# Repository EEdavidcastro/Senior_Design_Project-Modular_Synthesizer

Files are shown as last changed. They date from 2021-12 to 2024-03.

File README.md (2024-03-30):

# EE485-Senior Design Project-Modular_Synth
This is the Senior Design project done by David Castro and Eric Burgess at CSUF in the fall semester of 2021 (August 2021 - December 2021) on building an Analog Modular Synthesizer

A video of the behavior of the Modular synthesizer can be seen on partner's youtube channel - https://www.youtube.com/watch?v=jhq_Q-R4t1U

The report, presentation, and virtual poster for a summary of the probject are also posted on this repository:
- Video (Partner's Youtube Channel): https://www.youtube.com/watch?v=jhq_Q-R4t1U
- Report: https://github.com/EEdavidcastro/EE485-SeniorDesign-Modular_Synth/blob/main/485Final%20Report_DavidCastro_EricBurgess.pdf
- Presentation: https://github.com/EEdavidcastro/EE485-SeniorDesign-Modular_Synth/blob/main/485Final%20Presentation_DavidCastro_EricBurgess.pdf
- Virtual Poster: https://github.com/EEdavidcastro/EE485-SeniorDesign-Modular_Synth/blob/main/485Final%20Project%20Poster%20Outline_David%20Castro%26EricBurgess.pdf

Note about uploaded files in the circuit design:
  - KiCad files for pcb design
  - .ms14 files are CAD files done in multisim software to show simulation of a small portion of the circuit (important part)

Note about MIDI Design: <br>
 - The current MIDI instrument is a modified version of Elkayem’s midi2cv design done by a youtuber named
“Benny Bones.” The MIDI gerber files and code to run the MIDI is provided in this respository for ease. **The MIDI was not designed by us due to time contraints.**

Note on file labeling mistake:
- Current Source file has files inside named VCF, ignore the title/label of it being VCF, they are the current source files

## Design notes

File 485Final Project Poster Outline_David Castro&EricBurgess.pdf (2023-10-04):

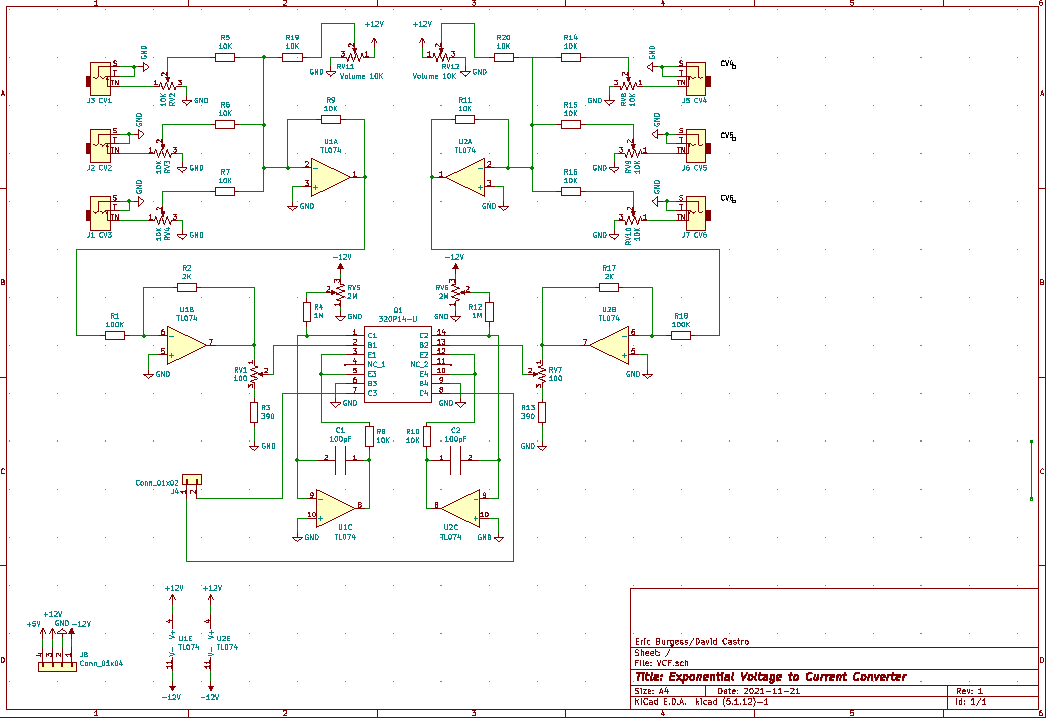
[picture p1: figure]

A modular synthesizer is an electronic device that consists of individual modules that can be connected by a user to create a music instrument. Modules specialize in a task such as creating a specific signal or affecting a signal in some way. For example, a sawtooth oscillator may be one module and a device to mix multiple signals together (a mixer) may be another. By connecting these devices together in various ways many sounds, and musical uses may be produced.

# Introduction

# Objectives

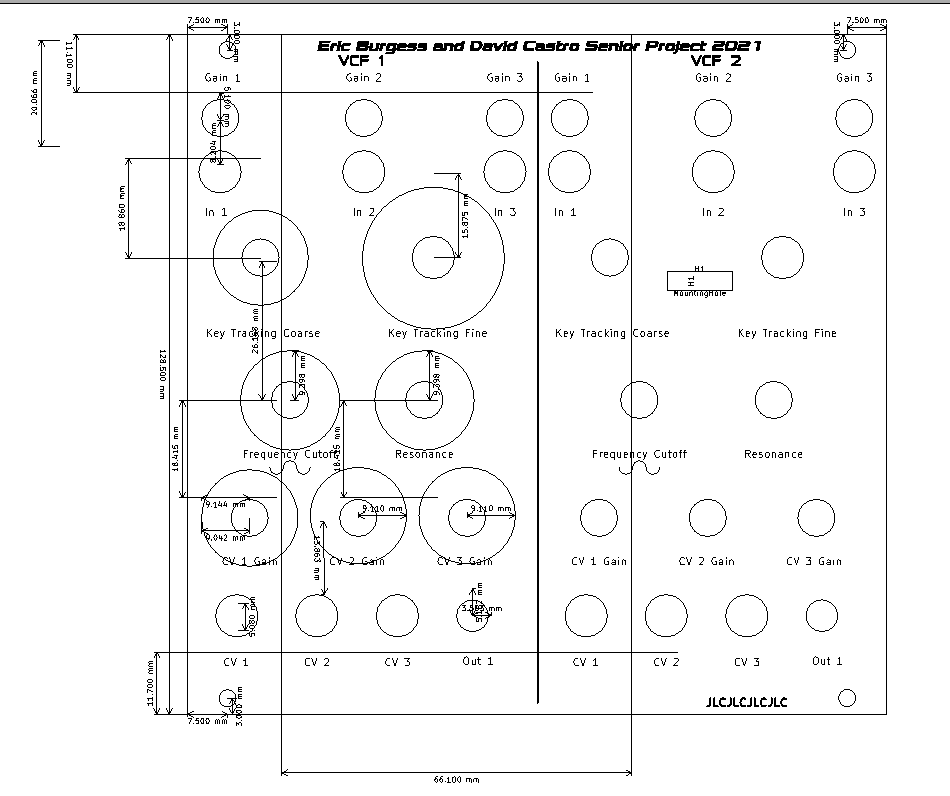
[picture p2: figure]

1. Circuits were designed and simulated in Multisim
2. The circuits were tested/built on a Bread board
3. Design EuroRack Standard Case
4. Were initially going to solder by hand, but decided upon using KiCad for PCB design and ordering the PCB’s from an online website
5. Panels/Covers were initially going to be done by hand but decided to use the KiCad and PCB material to act as the panels/covers
6. Solder the components onto the PCB and then screw everything together
7. Test and Debug the circuits to see if they properly work

# Steps of Design for Circuits

# Conclusion:

Power Supply
http://musicfromouterspace.com/analogsynth_new/WALLWARTSUPPLY/WALLWARTSUPPLY.phphttps://www.youtube.com/watch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

Synthesizer Modules
Textbook resources:
Musical Applications of Microprocessors (Hal Chamberlin) - chapter 6

Websites of Synthesizer Designs and Explanations: https://www.schmitzbits.de/expo_tutorial/index.html •ADSR design https://www.schmitzbits.de/adsr.htmlhttp://ijfritz.byethost4.com/sy_over.htm

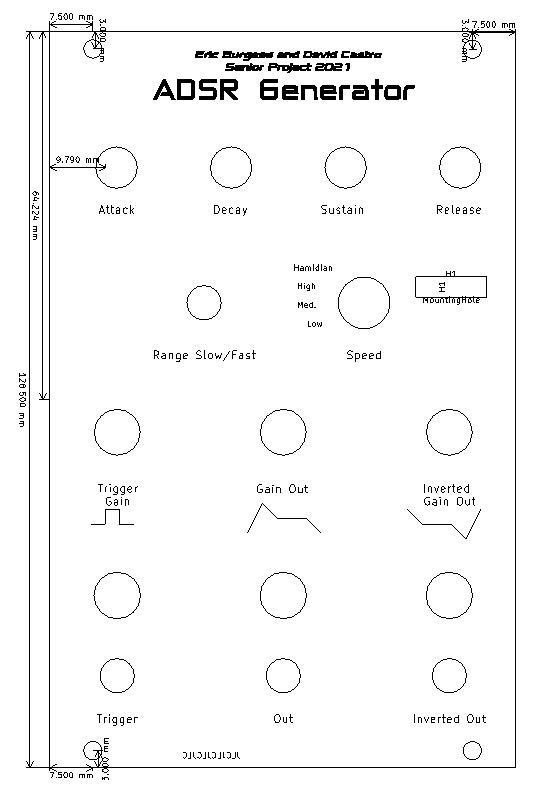
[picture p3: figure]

Georgia Tech Professor: - Aaron Lanterman Lectures:
VCA - https://www.youtube.com/watch?v=96j2tNKFCPI&t=202s
VCO - https://www.youtube.com/watch?v=qF4G4QfC9dM&t=699s
Exponential Voltage to Current - https://www.youtube.com/watch?v=ZWJhApUmfEU Playlist of Lectures:
https://www.youtube.com/playlist?list=PLOunECWxELQS5bMdWo9VhmZtsCjhjYNcV

Musical Instrument Digital Interface (MIDI)

Youtuber - Benny Bones: https://github.com/BennyBones/midi2cv

## GitHub Link of Final Report and all circuits and their designs in KiCad:

## https://github.com/EEdavidcastro/EE485-SeniorDesign-Modular_Synth

# Github Link

The end goal is to create enough modules and a variety of them to provide a versatile instrument. Specifically, we wish to create a power supply for the modules, an oscillator as a sound source, an ADSR envelope as a modulation signal, and a filter. All the modules should be voltage controlled, meaning they can be controlled by an input voltage from another module. A voltage to current exponential converter will be used to convert a controlled voltage (CV) to a controlled current. Doing this allows Operational Transconductance Amplifiers (OTA’s) to be used in circuit design as a way of adjusting each module. By having each module be voltage controlled, the modules will be able to interact and control each other.

# Layout of Voltage to Current Converter (KiCad)

Description: The circuit shows 2 voltage to current converter circuits. Each have 3 control voltage inputs that are mixed through an active mixing circuit. From there it flows through an op amp gain stage that is used to tune down the voltage that will flow into the base of a BJT differential pair. The IC chip (320P14) is just two matched differential pairs (PNP). Nearly the same circuit applies for the circuit above the sink version. The main difference is that NPN BJTS are used in the differential pair chip.

# Constraints of the Design

•The Power Supply will have outputs for +/- 12 Volts and +5 Volts. It will be able to take any U.S. standard outlet for supplying the power supply through a wall wart
•Patches to modules on the user side will be done with standard 3.5mm ⅛ inch mono jacks. Stereo jacks will be used where appropriate if needed.
•One Volt per octave is the standard for the voltage to current converters. This means for each volt, the current doubles meaning, the frequency of the oscillator will double. This is a common tuning standard so that voltages correspond with musical pitches.

# Voltage to Current Converter Circuit (source)

Description: The design were done in KiCad using the layout tool. It would be ideal for these to be done on aluminum sheets, but due the costs we decided on using PCB material, the same used for the circuits. This was done for each of the panels: VCA, VCF, ADSR Envelope, power supply, and MIDI device.

Description: The PCB board was designed as Though Hole (THT) with each of the chips, resistors, capacitors, etc inserted into the device. This process of PCB design is done for the VCO, VCA, and ADSR Envelope aswell.
Note: See Github link for the rest of the designs in KiCad

# Block Diagram

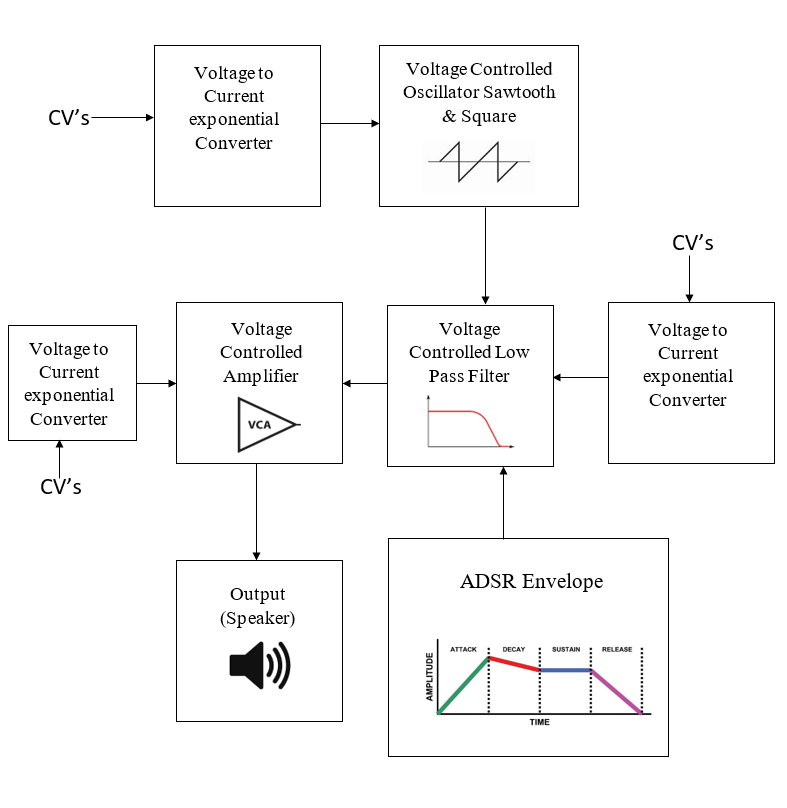
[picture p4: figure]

Description: This block diagram is an example of how the modules can be connected. The only thing standard is the CV’s and the voltage to current converters before each voltage-controlled module. A different way of connecting the modules could be having the ADSR envelope connected to the oscillator or amplifier instead

# Example of Cover Panel Design (VCF)

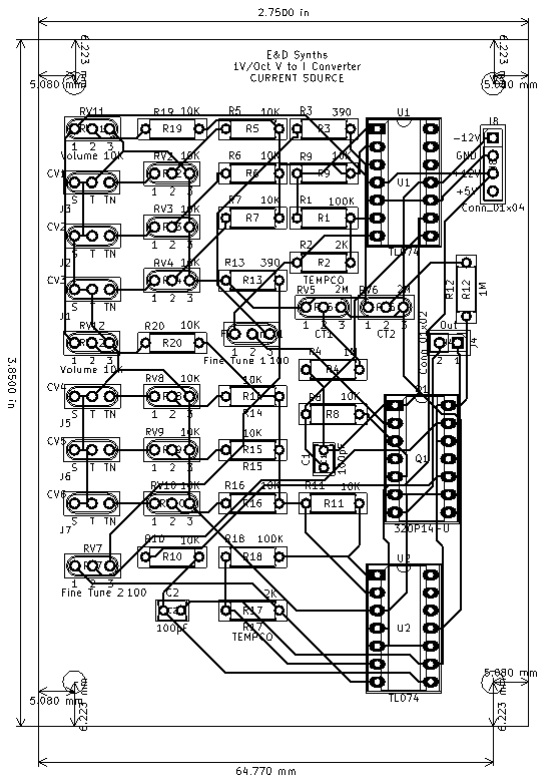
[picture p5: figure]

Description: Due to time constraint an auto router was used for the layout. KiCad does not have a built in autorouter, but there as exterior tool that can do autorouting of a KiCad design and then be imported. Besides the routing, each of the PCB’s were designed so that the screw holes would align up correctly with each other.

# Final Product Pictures:

# References

# Printed Board of Voltage to Current Converted:

There were many problems that came along the way in order to achieve the goal of this project. Some of the modules did not initially work and currently there are some things in the final product that need adjustment. The layout and schematic designs had some errors that caused the need for there to be some external wiring or modding of the PCB board. One example is that the +Vcc and -Vcc were mixed up on one IC which caused the need to do some wiring off board. This problem also occurred for the ADSR where the BJTS did not have the same pinout on the layout. Also, a few of the devices when put in the case ended up having some functionality problems. This occurs because there are many wires and no cable management which means the wires are most likely touching and creating connections when there should be none. One of the sawtooth oscillators for example is affected by the PWM adjustment of the square wave. This problem was not seen until the module was put in the case and is believed to be caused by some wires touching each other. Another problem seen when putting the module in the case is the VCF where for some reason things will stop working at certain moments or sometimes a potentiometer would affect the other VCF. These problems could be fixed with proper cable management, but overall, the modules can be seen as a success as things behave correctly for the most part. In conclusion, a modular synthesizer was achieved, but some things need to be ironed out for it to always work properly.

# Modular Synthesizer

# Eric Burgess and David Castro

# EE-485 Electrical Engineering Design Project Laboratory Fall 2021 Advisor - Dr. David Cheng

Inside Wiring
within the case

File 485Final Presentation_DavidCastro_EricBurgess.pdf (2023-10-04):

# Modular Synthesizer

# Eric Burgess and David Castro

## EE-485 Electrical Engineering Design Project Laboratory Fall 2021

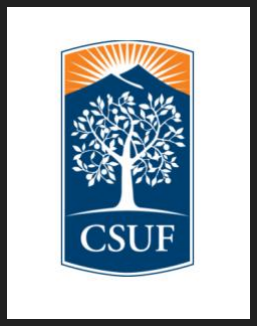
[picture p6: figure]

## Advisor - Dr. David Cheng

# What is a Synthesizer?

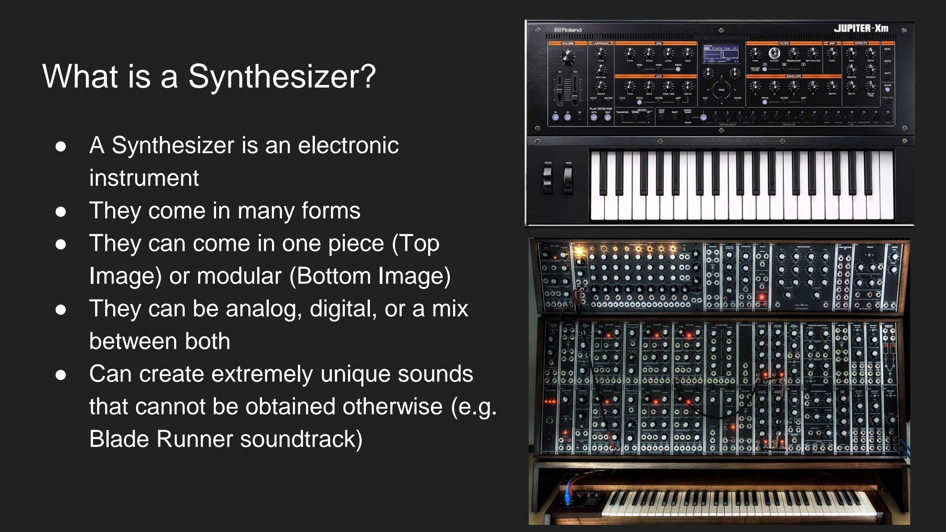
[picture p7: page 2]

## - A Synthesizer is an electronic instrument - They come in many forms - They can come in one piece (Top Image) or modular (Bottom Image) - They can be analog, digital, or a mix between both - Can create extremely unique sounds

that cannot be obtained otherwise (e.g.

## Blade Runner soundtrack)

# Our Synthesizer

## - We wanted a Modular Synthesizer

- Modular means each of the components are divided up - oscillators, filters, amplifiers, etc
- Benefits?
■ | Gives the user more freedom as things can be patched together by the user and there is
| not a set structure
- Components?
■ | VCO (Voltage Controlled Oscillator)
■ | VCA (Voltage Controlled Amplifier)
■ | VCF (Voltage Controlled Filter)
■ | ADSR Envelope Generator
■ | MIDI instrument
■ | Power Supply

# Block Diagram

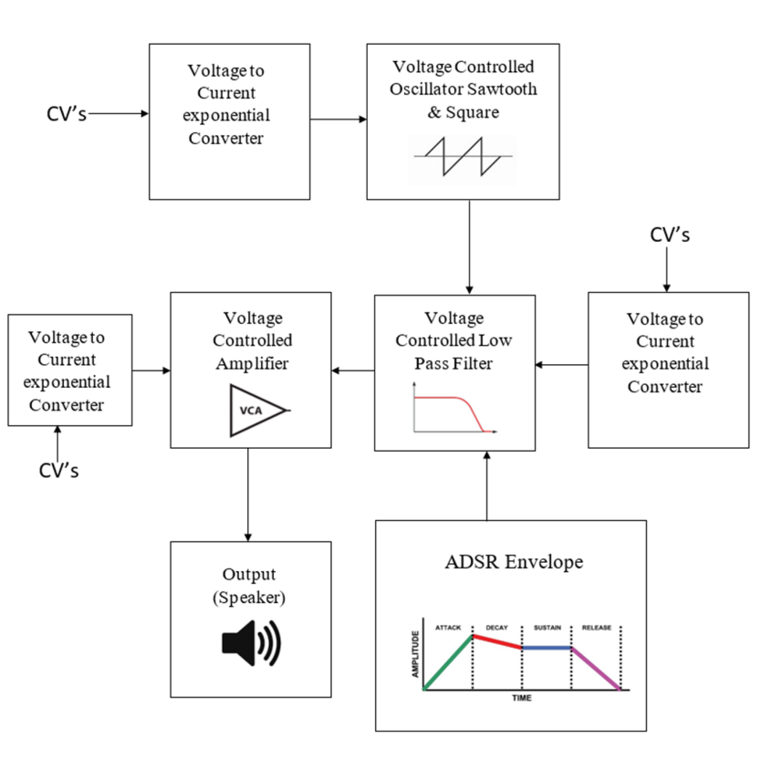
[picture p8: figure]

The system is modular, meaning the user can patch things together the way they want. The block diagram on the left is an example of how different modules can be connected

# Standards/Constraints

## Standards

### - 1 volt per Octave standard (This is a common tuning standard so that voltages correspond with musical pitches but we may choose to use another similar standard for the similar purpose of tuning)

## Constraints

### - Dual rail power supply. A positive and negative voltage will be available to run the system via a single wall wart. (+12V, -12V, GND) - Patches to modules on the user side will be done with standard 3.5mm ⅛ inch

mono jacks. Stereo jacks will be used where appropriate if needed.

# Power Supply Design

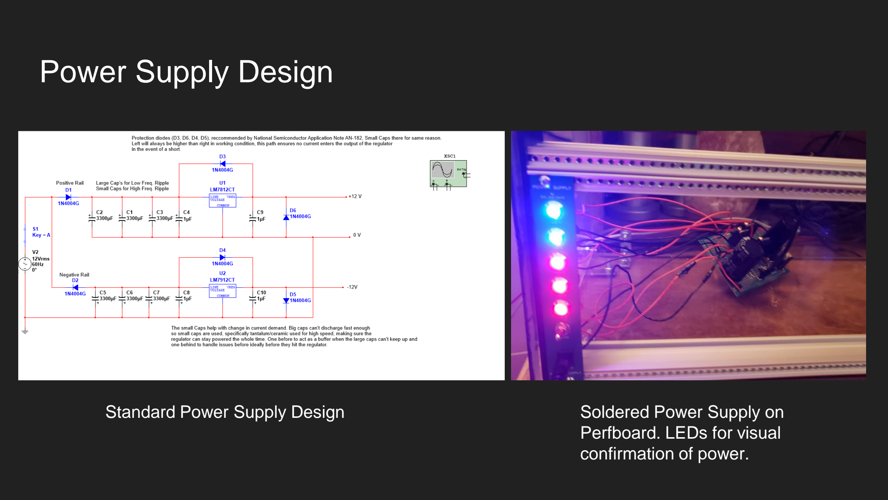
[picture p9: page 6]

Standard Power Supply Design | Soldered Power Supply on Perfboard. LEDs for visual confirmation of power.

# Another Picture of Power Supply

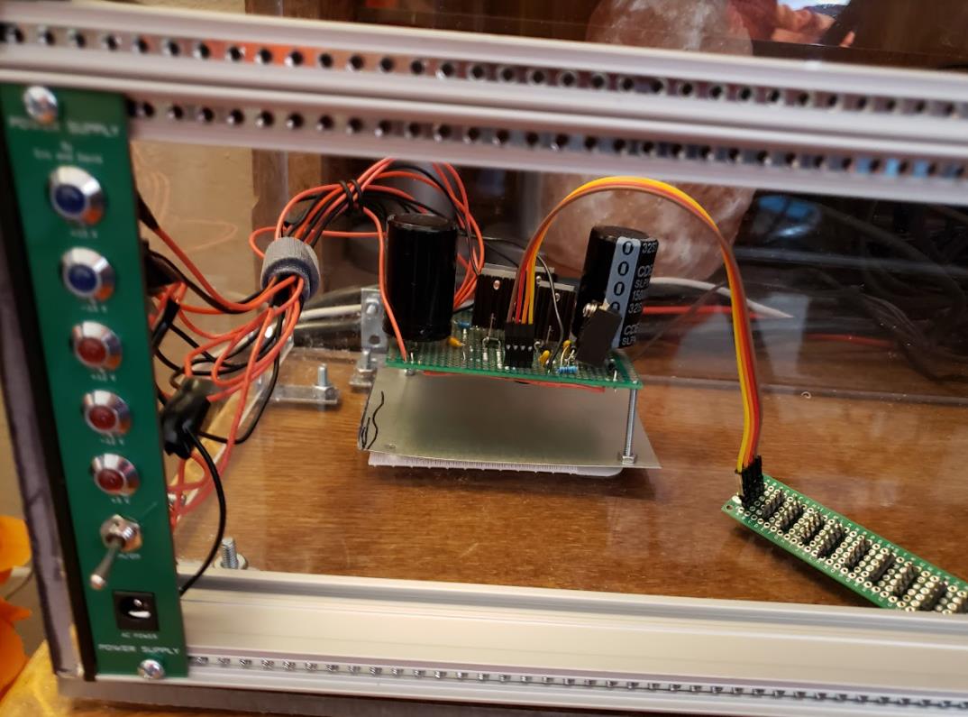
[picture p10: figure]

# VCO

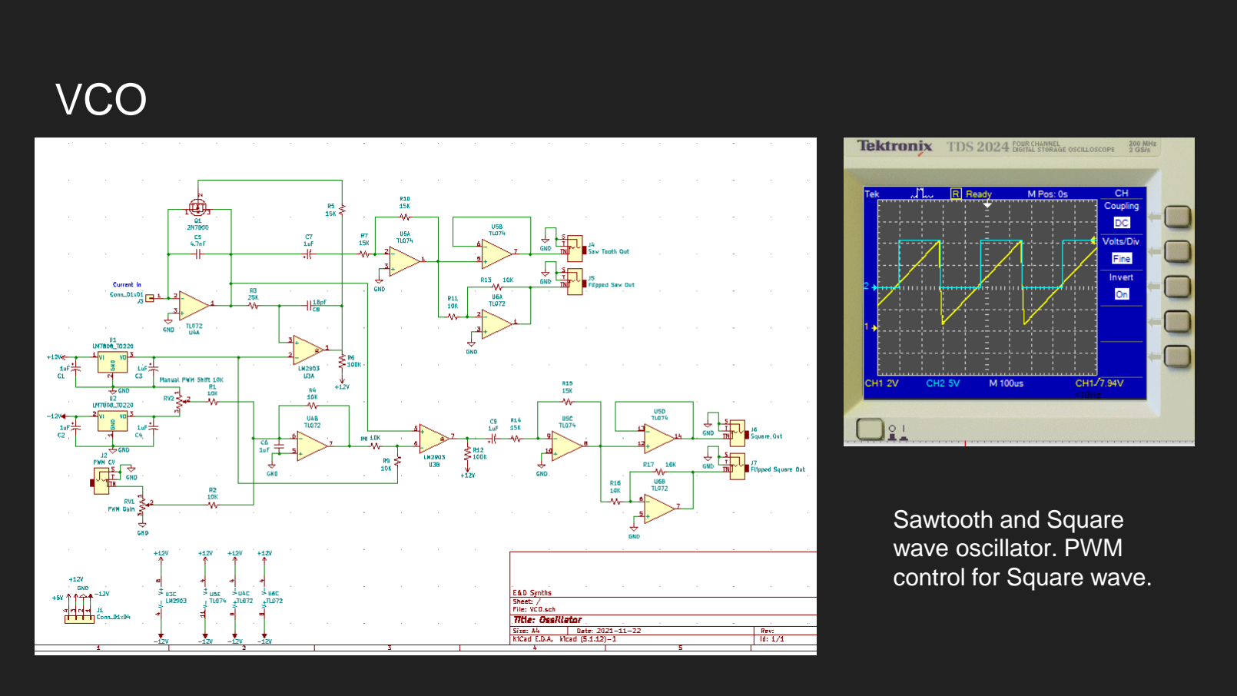
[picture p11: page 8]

Sawtooth and Square
wave oscillator. PWM
control for Square wave.

# VCF (Low-Pass)

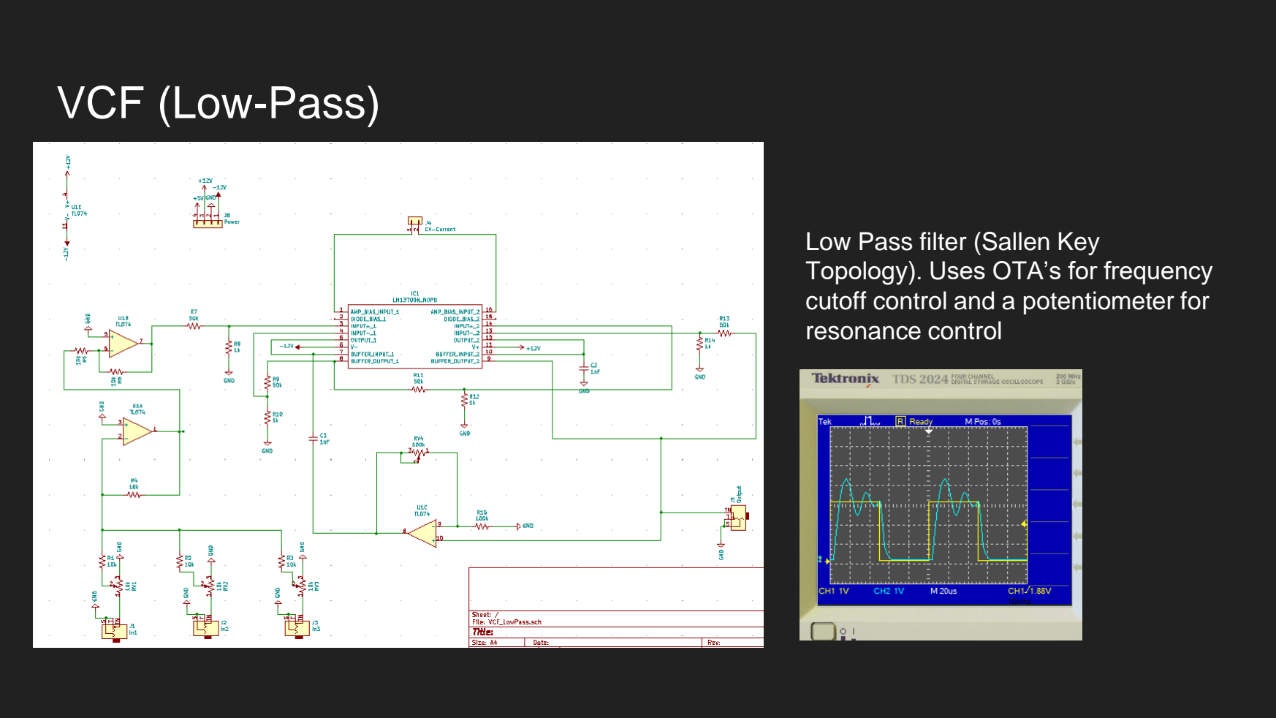
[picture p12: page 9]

Low Pass filter (Sallen Key Topology). Uses OTA’s for frequency cutoff control and a potentiometer for resonance control

# VCA

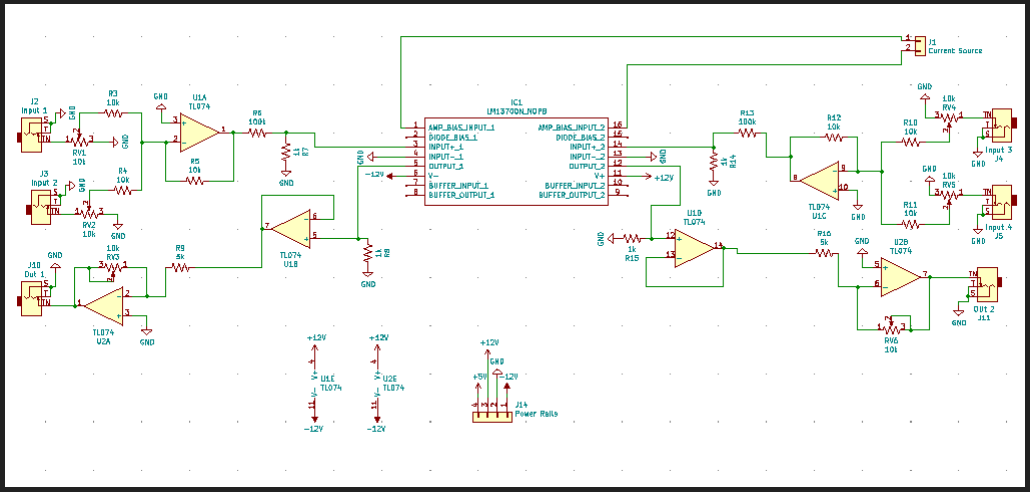
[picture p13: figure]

Uses OTA’s for
amplification. The
design has two
amplifiers on one
board.

# ADSR Envelope Generator

A - Attack
D - Decay
S - Sustain
R - Release

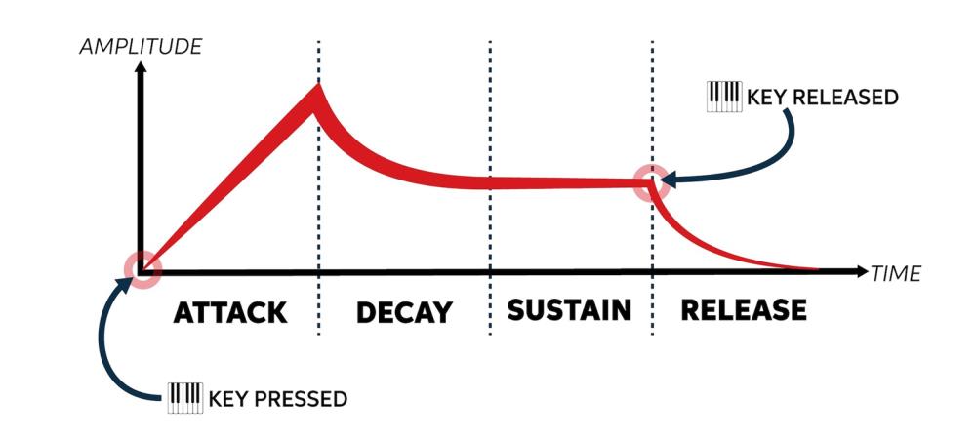
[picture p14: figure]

Important because its a voltage signal that can be adjusted. Our modules are voltage controlled so this can control the oscillator, filter, amplifier, etc

# ADSR Circuit

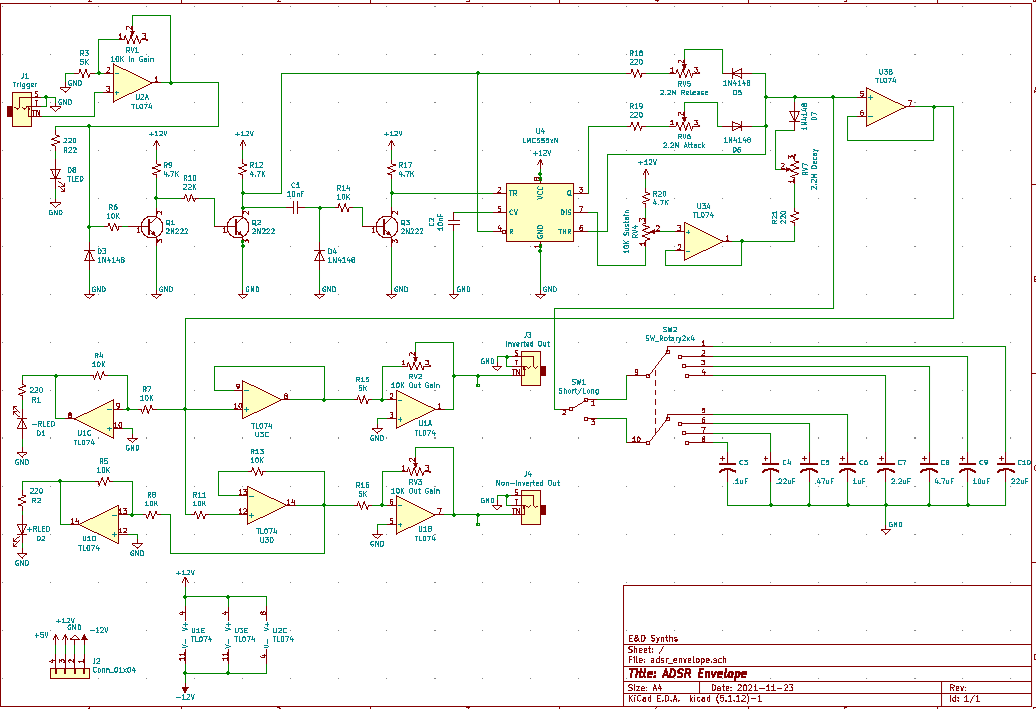
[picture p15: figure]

Capacitors control the time constant (charge and discharge rate). This design allows the user to switch between capacitors for different speeds in the ADSR

# Used KiCad for PCB Design

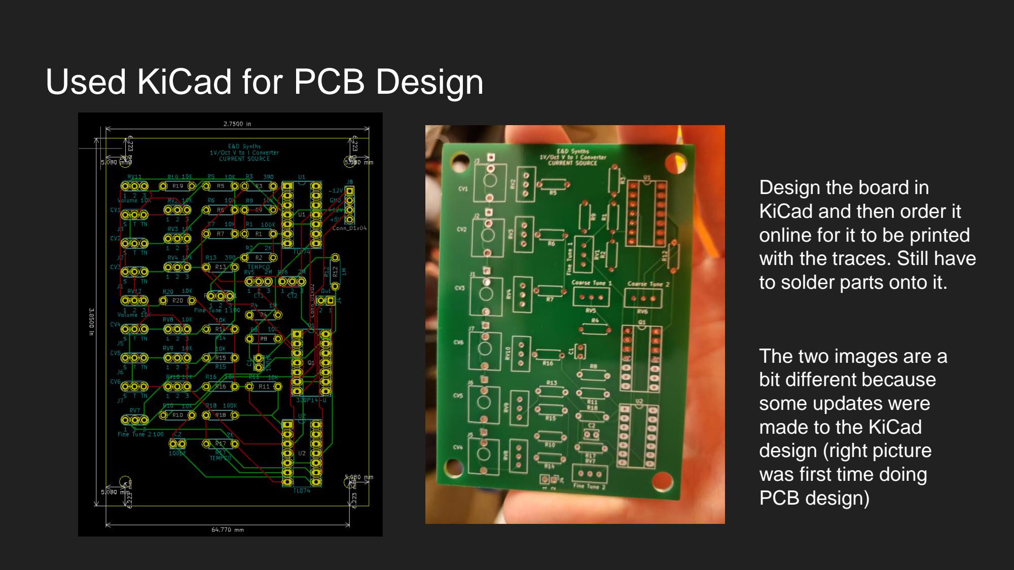
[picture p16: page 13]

Design the board in
KiCad and then order it
online for it to be printed with the traces. Still have to solder parts onto it.

The two images are a
bit different because
some updates were
made to the KiCad
design (right picture
was first time doing
PCB design)

# Completed ADSR

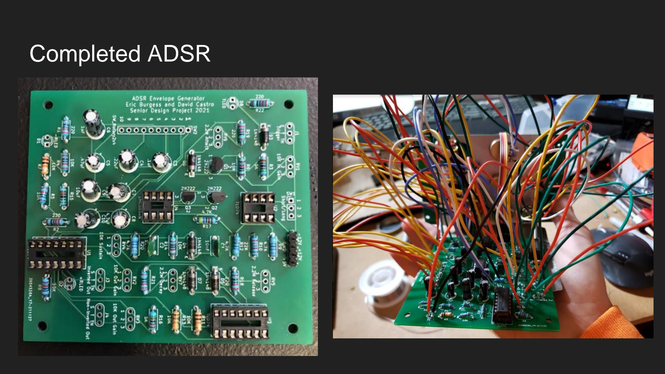
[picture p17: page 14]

# Putting Multiple Boards together

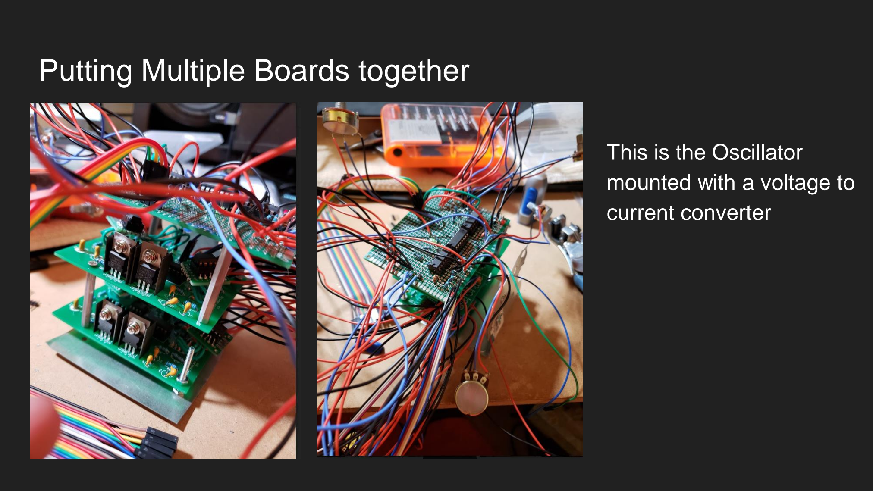
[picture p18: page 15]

## This is the Oscillator mounted with a voltage to current converter

# Panel Design (Done in KiCad)

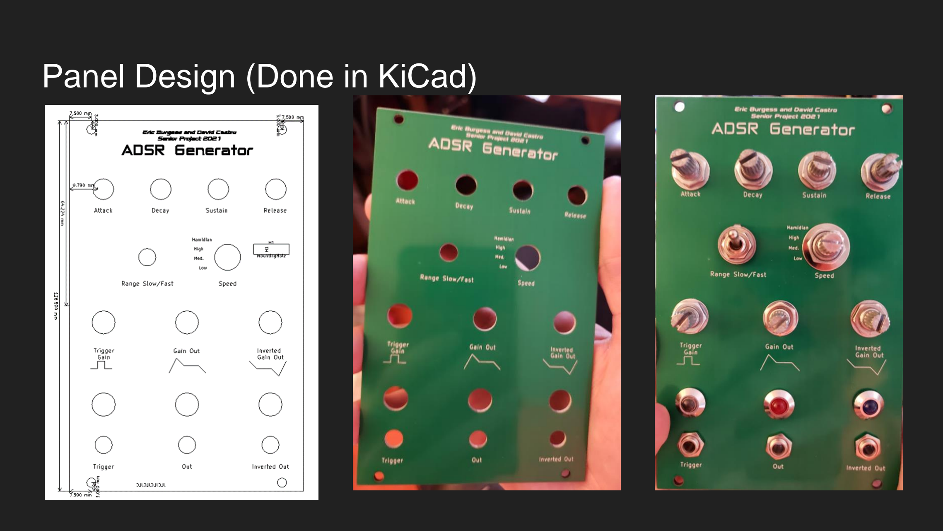
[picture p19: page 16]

# Mounting the Panel and PCB Board Together

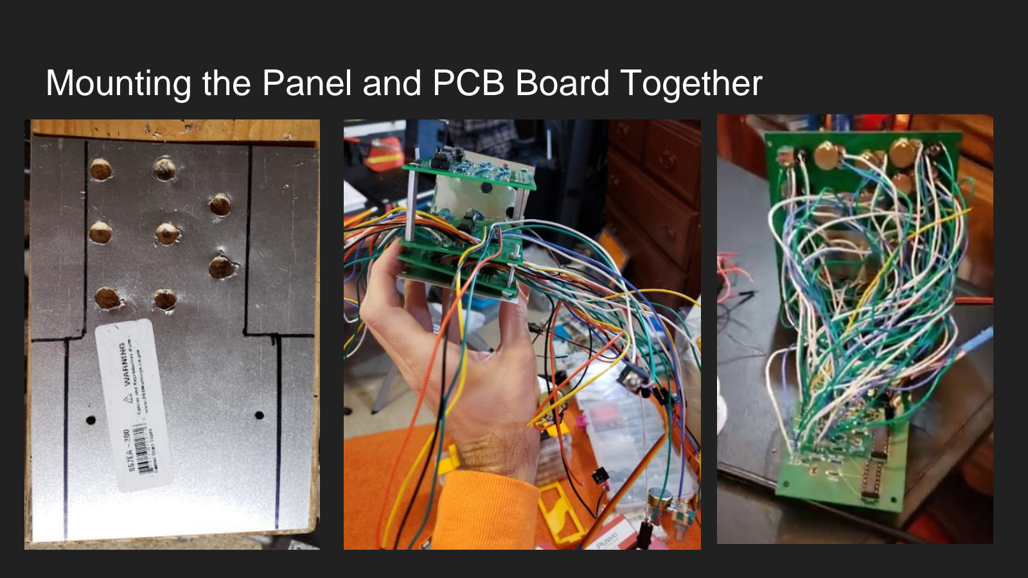
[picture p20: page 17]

# Case Design (EuroRack Standard)

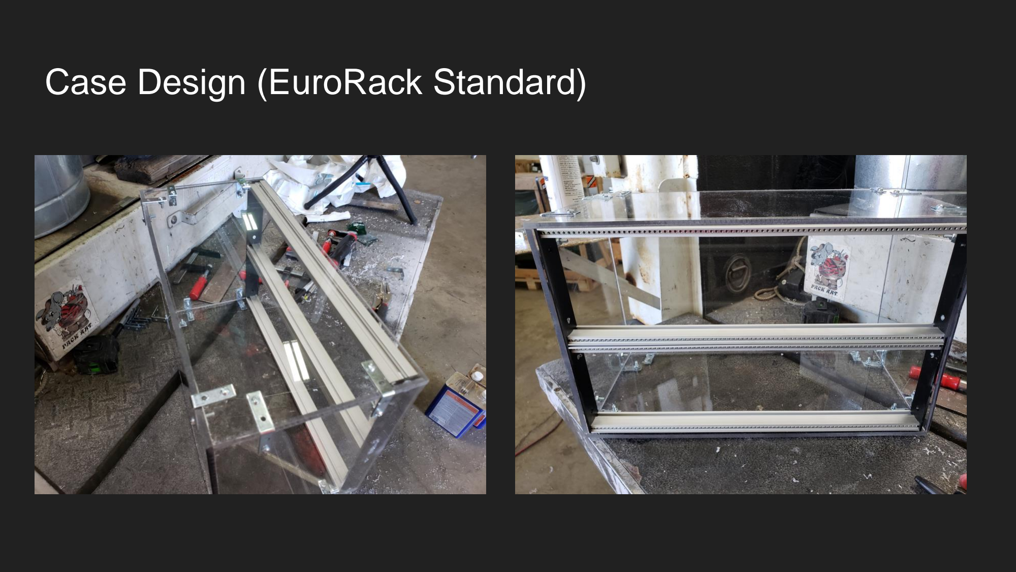
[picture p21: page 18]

# Final Product

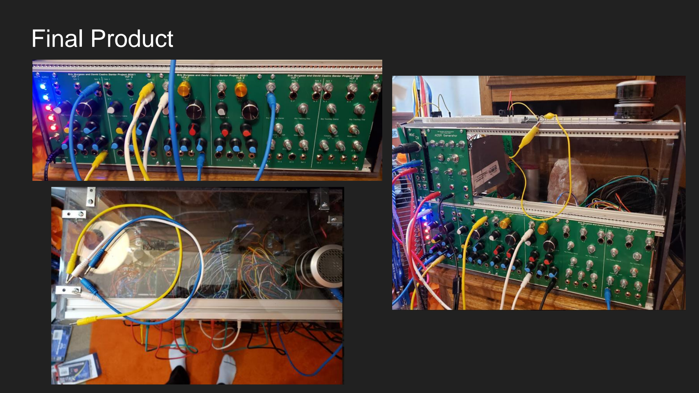
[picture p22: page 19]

# Does it work?

- It works. Although there was a lot of debugging/testing because the schematics/layouts had some slight errors - The VCF is the only really buggy module. The potentiometers/knobs affect things inconsistently. We believe this occurs because the wiring in the back is touching each other causing connections that shouldn’t be occurring - One of the sawtooths of the VCO’s also gets affected by the PWM. We know this is a cable management problem because this problem only started occurring when we put it in the case - Besides these two problems, things are good

# Last Topic - MIDI Instrument

- Musical Instrument Digital Interface (MIDI) - Outputs pulses (1’s and 0’s (Digital Signals)) as CV’s that end up getting converted to analog voltage signals through a Digital to Analog Converter and can then be fed into any of the modules - Important because it allows easy interface for the modules

# Some Video Links (Not the Final Product)

https://drive.google.com/file/d/1J7yfCgqspWNE97duwDbHwXujPmt6Wm02/view?usp=sharing -This showcases us debugging/testing the modules a bit

https://drive.google.com/file/d/1u8E_wDMR5lwQMjyUZ2qSCMlq0Rg5-qJn/view?usp=sharing -This one shows us testing the filter a bit

https://drive.google.com/file/d/1MLvvsz7yZ2b3NFyEDO3lgpPcuzt6oSCv/view?usp=sharing -Shows the frequency modulation that can be outputted from the Oscillator by inputting a control voltage from another oscillator

https://drive.google.com/file/d/1TYD_inGY7WyK13ahnys_tnFNM8BbnNII/view?usp=sharing - This one shows the VCO, VCA, and VCF working together (No ADSR or MIDI)

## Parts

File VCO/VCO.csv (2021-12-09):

Reference | Quantity | Value | Footprint | Datasheet
C1 C2 C3 C4 | 4 | 1uF | Capacitor_THT:CP_Radial_Tantal_D4.5mm_P2.50mm | ~
C5 | 1 | 4.7nF | Capacitor_THT:C_Disc_D6.0mm_W2.5mm_P5.00mm | ~
C6 | 1 | 1uF | Capacitor_THT:C_Disc_D6.0mm_W2.5mm_P5.00mm | ~
C7 C9 | 2 | 1uF | Capacitor_THT:CP_Radial_D6.3mm_P2.50mm | ~
C8 | 1 | 18pF | Capacitor_THT:C_Disc_D3.4mm_W2.1mm_P2.50mm | ~
J1 | 1 | Conn_01x04 | Connector_PinHeader_2.54mm:PinHeader_1x04_P2.54mm_Vertical | ~
J2 | 1 | PWM CV | Connector_Audio:Jack_3.5mm_QingPu_WQP-PJ398SM_Vertical_CircularHoles | ~
J3 | 1 | Conn_01x01 | Connector_PinHeader_2.54mm:PinHeader_1x01_P2.54mm_Vertical | ~
J4 | 1 | Saw Tooth Out | Connector_Audio:Jack_3.5mm_QingPu_WQP-PJ398SM_Vertical_CircularHoles | ~
J5 | 1 | Flipped Saw Out | Connector_Audio:Jack_3.5mm_QingPu_WQP-PJ398SM_Vertical_CircularHoles | ~
J6 | 1 | Square Out | Connector_Audio:Jack_3.5mm_QingPu_WQP-PJ398SM_Vertical_CircularHoles | ~
J7 | 1 | Flipped Square Out | Connector_Audio:Jack_3.5mm_QingPu_WQP-PJ398SM_Vertical_CircularHoles | ~
Q1 | 1 | 2N7000 | Package_TO_SOT_THT:TO-92L_HandSolder | ~
R1 R2 R4 R8 R9 R11 R13 R16 R17 | 9 | 10K | Resistor_THT:R_Axial_DIN0207_L6.3mm_D2.5mm_P7.62mm_Horizontal | ~
R3 | 1 | 25K | Resistor_THT:R_Axial_DIN0207_L6.3mm_D2.5mm_P7.62mm_Horizontal | ~
R5 R7 R10 R14 R15 | 5 | 15K | Resistor_THT:R_Axial_DIN0207_L6.3mm_D2.5mm_P7.62mm_Horizontal | ~
R6 R12 | 2 | 100K | Resistor_THT:R_Axial_DIN0207_L6.3mm_D2.5mm_P7.62mm_Horizontal | ~
RV1 | 1 | 10K | ECAD Models:Potentiometer_BaiHuiWeiYe | ~
RV2 | 1 | Manual PWM Shift 10K | ECAD Models:Potentiometer_BaiHuiWeiYe | ~
U1 U2 | 2 | LM7808_TO220 | Package_TO_SOT_THT:TO-220-3_Vertical | https://www.onsemi.cn/PowerSolutions/document/MC7800-D.PDF
U3 | 1 | LM2903 | Package_DIP:DIP-8_W7.62mm_Socket_LongPads | http://www.ti.com/lit/ds/symlink/lm393.pdf
U4 U6 | 2 | TL072 | Package_DIP:DIP-8_W7.62mm_Socket_LongPads | http://www.ti.com/lit/ds/symlink/tl071.pdf
U5 | 1 | TL074 | Package_DIP:DIP-14_W7.62mm_Socket_LongPads | http://www.ti.com/lit/ds/symlink/tl071.pdf

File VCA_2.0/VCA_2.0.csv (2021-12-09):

Source: | C:\Users\David Castro\Downloads\Senior Project\Senior Project\VCA_2.0\VCA_2.0.sch
Date: | 11/27/2021 6:58:21 PM
Tool: | Eeschema (5.1.12)-1
Generator: | D:\kicad\bin\scripting\plugins/bom_csv_grouped_by_value.py
Component Count: | 31
Individual Components:
Item | Qty | Reference(s) | Value | LibPart | Footprint | Datasheet | Description | Height | Manufacturer_Name | Manufacturer_Part_Number | Mouser Part Number | Mouser Price/Stock
 |  | IC1 | LM13700N_NOPB | SamacSys_Parts:LM13700N_NOPB | Package_DIP:DIP-16_W7.62mm_Socket_LongPads | http://www.ti.com/lit/ds/symlink/lm13700.pdf | Dual transconductance op amp,LM13700N Texas Instruments LM13700N/NOPB Dual Operational Amplifier Transconductance, 2MHz Push-Pull 3 to 28V, 16-Pin MDIP | 4.318 | Texas Instruments | LM13700N/NOPB | 926-LM13700N/NOPB | https://www.mouser.co.uk/ProductDetail/Texas-Instruments/LM13700N-NOPB?qs=X1J7HmVL2ZFKw9D7azZDXw%3D%3D
 |  | J1 | Current Source | Connector_Generic:Conn_01x02 | Connector_PinHeader_2.54mm:PinHeader_1x02_P2.54mm_Vertical | ~
 |  | J2 | Input 1 | Connector:AudioJack2_SwitchT | custom:THONK-AudioJack-PJ398SM-W3.5mm | ~
 |  | J3 | Input 2 | Connector:AudioJack2_SwitchT | custom:THONK-AudioJack-PJ398SM-W3.5mm | ~
 |  | J4 | Input 3 | Connector:AudioJack2_SwitchT | custom:THONK-AudioJack-PJ398SM-W3.5mm | ~
 |  | J5 | Input 4 | Connector:AudioJack2_SwitchT | custom:THONK-AudioJack-PJ398SM-W3.5mm | ~
 |  | J10 | Out 1 | Connector:AudioJack2_SwitchT | custom:THONK-AudioJack-PJ398SM-W3.5mm | ~
 |  | J11 | OUt 2 | Connector:AudioJack2_SwitchT | custom:THONK-AudioJack-PJ398SM-W3.5mm | ~
 |  | J14 | Power Rails | Connector_Generic:Conn_01x04 | Connector_PinHeader_2.54mm:PinHeader_1x04_P2.54mm_Vertical | ~
 |  | R3 | 10k | Device:R_US | Resistor_THT:R_Axial_DIN0207_L6.3mm_D2.5mm_P7.62mm_Horizontal | ~
 |  | R4 | 10k | Device:R_US | Resistor_THT:R_Axial_DIN0207_L6.3mm_D2.5mm_P7.62mm_Horizontal | ~
 |  | R5 | 10k | Device:R_US | Resistor_THT:R_Axial_DIN0207_L6.3mm_D2.5mm_P7.62mm_Horizontal | ~
 |  | R6 | 100k | Device:R_US | Resistor_THT:R_Axial_DIN0207_L6.3mm_D2.5mm_P7.62mm_Horizontal | ~
 |  | R7 | 1k | Device:R_US | Resistor_THT:R_Axial_DIN0207_L6.3mm_D2.5mm_P7.62mm_Horizontal | ~
 |  | R8 | 1k | Device:R_US | Resistor_THT:R_Axial_DIN0207_L6.3mm_D2.5mm_P7.62mm_Horizontal | ~
 |  | R9 | 5k | Device:R_US | Resistor_THT:R_Axial_DIN0207_L6.3mm_D2.5mm_P7.62mm_Horizontal | ~
 |  | R10 | 10k | Device:R_US | Resistor_THT:R_Axial_DIN0207_L6.3mm_D2.5mm_P7.62mm_Horizontal | ~
 |  | R11 | 10k | Device:R_US | Resistor_THT:R_Axial_DIN0207_L6.3mm_D2.5mm_P7.62mm_Horizontal | ~
 |  | R12 | 10k | Device:R_US | Resistor_THT:R_Axial_DIN0207_L6.3mm_D2.5mm_P7.62mm_Horizontal | ~
 |  | R13 | 100k | Device:R_US | Resistor_THT:R_Axial_DIN0207_L6.3mm_D2.5mm_P7.62mm_Horizontal | ~
 |  | R14 | 1k | Device:R_US | Resistor_THT:R_Axial_DIN0207_L6.3mm_D2.5mm_P7.62mm_Horizontal | ~
 |  | R15 | 1k | Device:R_US | Resistor_THT:R_Axial_DIN0207_L6.3mm_D2.5mm_P7.62mm_Horizontal | ~
 |  | R16 | 5k | Device:R_US | Resistor_THT:R_Axial_DIN0207_L6.3mm_D2.5mm_P7.62mm_Horizontal | ~
 |  | RV1 | 10k | Device:R_POT_US | custom:POT_3_THT | ~
 |  | RV2 | 10k | Device:R_POT_US | custom:POT_3_THT | ~
 |  | RV3 | 10k | Device:R_POT_US | custom:POT_3_THT | ~
 |  | RV4 | 10k | Device:R_POT_US | custom:POT_3_THT | ~
 |  | RV5 | 10k | Device:R_POT_US | custom:POT_3_THT | ~
 |  | RV6 | 10k | Device:R_POT_US | custom:POT_3_THT | ~
 |  | U1 | TL074 | Amplifier_Operational:TL074 | Package_DIP:DIP-14_W7.62mm_Socket_LongPads | http://www.ti.com/lit/ds/symlink/tl071.pdf
 |  | U2 | TL074 | Amplifier_Operational:TL074 | Package_DIP:DIP-14_W7.62mm_Socket_LongPads | http://www.ti.com/lit/ds/symlink/tl071.pdf
Collated Components:
Item | Qty | Reference(s) | Value | LibPart | Footprint | Datasheet | Description | Height | Manufacturer_Name | Manufacturer_Part_Number | Mouser Part Number | Mouser Price/Stock
1 | 1 | IC1 | LM13700N_NOPB | SamacSys_Parts:LM13700N_NOPB | Package_DIP:DIP-16_W7.62mm_Socket_LongPads | http://www.ti.com/lit/ds/symlink/lm13700.pdf | Dual transconductance op amp,LM13700N Texas Instruments LM13700N/NOPB Dual Operational Amplifier Transconductance, 2MHz Push-Pull 3 to 28V, 16-Pin MDIP | 4.318 | Texas Instruments | LM13700N/NOPB | 926-LM13700N/NOPB | https://www.mouser.co.uk/ProductDetail/Texas-Instruments/LM13700N-NOPB?qs=X1J7HmVL2ZFKw9D7azZDXw%3D%3D
2 | 1 | J1 | Current Source | Connector_Generic:Conn_01x02 | Connector_PinHeader_2.54mm:PinHeader_1x02_P2.54mm_Vertical | ~
3 | 1 | J2 | Input 1 | Connector:AudioJack2_SwitchT | custom:THONK-AudioJack-PJ398SM-W3.5mm | ~
4 | 1 | J3 | Input 2 | Connector:AudioJack2_SwitchT | custom:THONK-AudioJack-PJ398SM-W3.5mm | ~
5 | 1 | J4 | Input 3 | Connector:AudioJack2_SwitchT | custom:THONK-AudioJack-PJ398SM-W3.5mm | ~
6 | 1 | J5 | Input 4 | Connector:AudioJack2_SwitchT | custom:THONK-AudioJack-PJ398SM-W3.5mm | ~
7 | 1 | J10 | Out 1 | Connector:AudioJack2_SwitchT | custom:THONK-AudioJack-PJ398SM-W3.5mm | ~
8 | 1 | J11 | OUt 2 | Connector:AudioJack2_SwitchT | custom:THONK-AudioJack-PJ398SM-W3.5mm | ~
9 | 1 | J14 | Power Rails | Connector_Generic:Conn_01x04 | Connector_PinHeader_2.54mm:PinHeader_1x04_P2.54mm_Vertical | ~
10 | 6 | R3, R4, R5, R10, R11, R12 | 10k | Device:R_US | Resistor_THT:R_Axial_DIN0207_L6.3mm_D2.5mm_P7.62mm_Horizontal | ~
11 | 2 | R6, R13 | 100k | Device:R_US | Resistor_THT:R_Axial_DIN0207_L6.3mm_D2.5mm_P7.62mm_Horizontal | ~
12 | 4 | R7, R8, R14, R15 | 1k | Device:R_US | Resistor_THT:R_Axial_DIN0207_L6.3mm_D2.5mm_P7.62mm_Horizontal | ~
13 | 2 | R9, R16 | 5k | Device:R_US | Resistor_THT:R_Axial_DIN0207_L6.3mm_D2.5mm_P7.62mm_Horizontal | ~
14 | 6 | RV1, RV2, RV3, RV4, RV5, RV6 | 10k | Device:R_POT_US | custom:POT_3_THT | ~
15 | 2 | U1, U2 | TL074 | Amplifier_Operational:TL074 | Package_DIP:DIP-14_W7.62mm_Socket_LongPads | http://www.ti.com/lit/ds/symlink/tl071.pdf

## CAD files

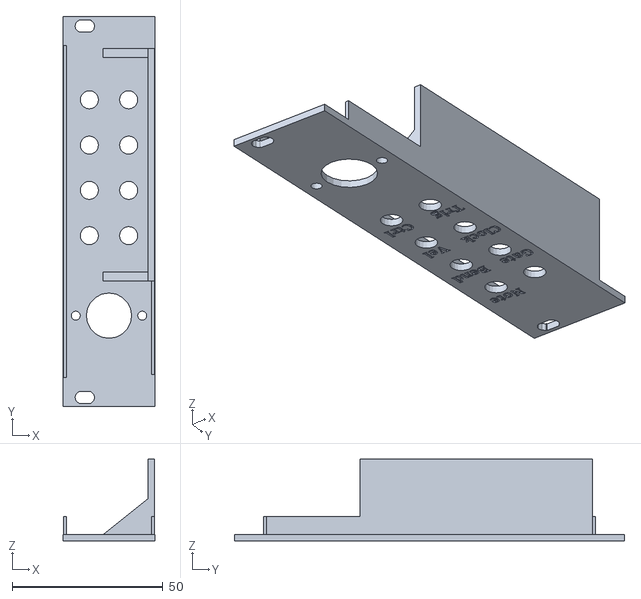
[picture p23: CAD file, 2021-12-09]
midi2cv-master/3dPrint/CV2Midi_face.stl
30.5 x 129.2 x 27.0

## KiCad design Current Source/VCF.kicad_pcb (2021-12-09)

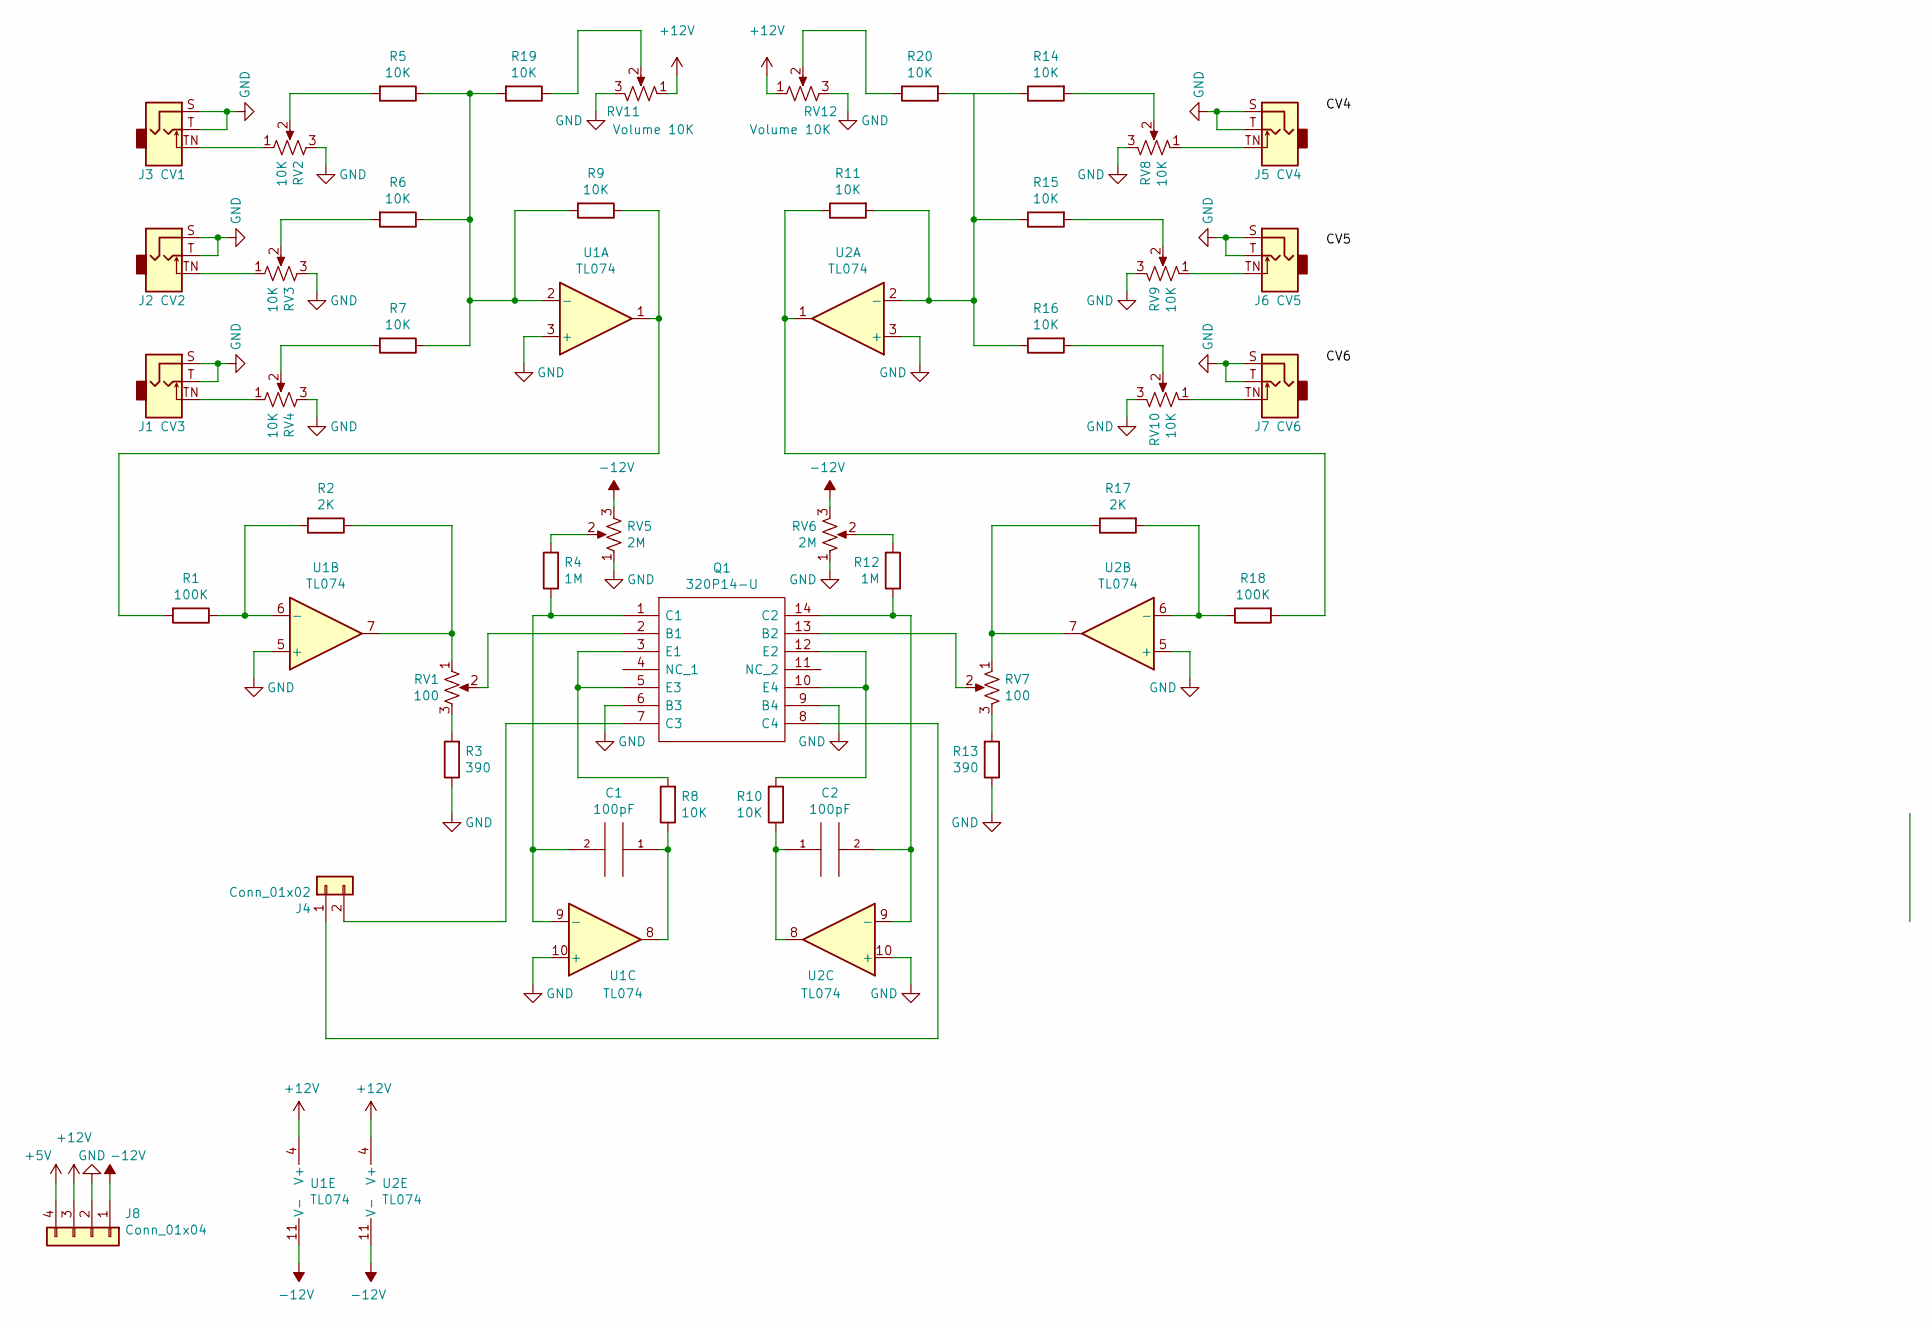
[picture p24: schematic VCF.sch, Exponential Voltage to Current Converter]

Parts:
C1, C2: 100pF; C_Disc_D3.8mm_W2.6mm_P2.50mm
J1: CV3; Thonkiconn_Audio_Jack_PJ398SM_W7.0mm_H2.5mm
J2: CV2; Thonkiconn_Audio_Jack_PJ398SM_W7.0mm_H2.5mm
J3: CV1; Thonkiconn_Audio_Jack_PJ398SM_W7.0mm_H2.5mm
J4: Conn_01x02; PinHeader_1x02_P2.54mm_Vertical
J5: CV4; Thonkiconn_Audio_Jack_PJ398SM_W7.0mm_H2.5mm
J6: CV5; Thonkiconn_Audio_Jack_PJ398SM_W7.0mm_H2.5mm
J7: CV6; Thonkiconn_Audio_Jack_PJ398SM_W7.0mm_H2.5mm
J8: Conn_01x04; PinHeader_1x04_P2.54mm_Vertical
Q1: 320P14-U; DIP-14_W7.62mm_Socket_LongPads; Manufacturer_Part_Number 320P14-U; Mouser Part Number 887-320P14-U
R1, R18: 100K; R_Axial_DIN0207_L6.3mm_D2.5mm_P7.62mm_Horizontal
R2, R17: 2K; R_Axial_DIN0207_L6.3mm_D2.5mm_P7.62mm_Horizontal
R3, R13: 390; R_Axial_DIN0207_L6.3mm_D2.5mm_P7.62mm_Horizontal
R4, R12: 1M; R_Axial_DIN0207_L6.3mm_D2.5mm_P7.62mm_Horizontal
R5, R6, R7, R8, R9, R10, R11, R14, R15, R16, R19, R20: 10K; R_Axial_DIN0207_L6.3mm_D2.5mm_P7.62mm_Horizontal
RV1, RV7: 100; Pot_Small_Mounting_W7.0mm_H2.5mm
RV2, RV3, RV4, RV8, RV9, RV10: 10K; Pot_Small_Mounting_W7.0mm_H2.5mm
RV5, RV6: 2M; Pot_Small_Mounting_W7.0mm_H2.5mm
RV11, RV12: Volume 10K; Pot_Small_Mounting_W7.0mm_H2.5mm
U1, U2: TL074; DIP-14_W7.62mm_Socket_LongPads

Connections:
+5V: J8.4
+12V: J8.3, RV11.1, RV12.1, U1.4 (V+), U2.4 (V+)
-12V: J8.1, RV5.3, RV6.3, U1.11 (V-), U2.11 (V-)
GND: J1.S, J1.T, J2.S, J2.T, J3.S, J3.T, J5.S, J5.T, J6.S, J6.T, J7.S, J7.T, J8.2, Q1.6 (B3), Q1.9 (B4), R3.1, R13.1, RV2.3, RV3.3, RV4.3, RV5.1, RV6.1, RV8.3, RV9.3, RV10.3, RV11.3, RV12.3, U1.3 (+), U1.5 (+), U1.10 (+), U2.3 (+), U2.5 (+), U2.10 (+)
unnamed: C1.1, R8.1, U1.8
unnamed: C1.2, Q1.1 (C1), R4.1, U1.9 (-)
unnamed: C2.1, R10.1, U2.8
unnamed: C2.2, Q1.14 (C2), R12.1, U2.9 (-)
unnamed: J1.TN, RV4.1
unnamed: J2.TN, RV3.1
unnamed: J3.TN, RV2.1
unnamed: J4.1, Q1.8 (C4)
unnamed: J4.2, Q1.7 (C3)
unnamed: J5.TN, RV8.1
unnamed: J6.TN, RV9.1
unnamed: J7.TN, RV10.1
unnamed 16: Q1.2 (B1), RV1.2; also elsewhere on the board
unnamed: Q1.3 (E1), Q1.5 (E3), R8.2
unnamed: Q1.10 (E4), Q1.12 (E2), R10.2
unnamed: Q1.13 (B2), RV7.2
unnamed: R1.1, R2.2, U1.6 (-)
unnamed: R1.2, R9.1, U1.1
unnamed 24: R2.1, RV1.1, U1.7; also elsewhere on the board
unnamed 25: R3.2, RV1.3; also elsewhere on the board
unnamed: R4.2, RV5.2
unnamed: R5.2, RV2.2
unnamed: R6.2, RV3.2
unnamed: R7.2, RV4.2
unnamed: R11.1, R18.2, U2.1
unnamed: R11.2, R14.1, R15.1, R16.1, R20.2, U2.2 (-)
unnamed: R12.2, RV6.2
unnamed: R13.2, RV7.3
unnamed: R14.2, RV8.2
unnamed: R15.2, RV9.2
unnamed: R16.2, RV10.2
unnamed: R17.1, RV7.1, U2.7
unnamed: R17.2, R18.1, U2.6 (-)
unnamed: R19.1, RV11.2
unnamed: R5.1, R6.1, R7.1, R9.2, R19.2, U1.2 (-)
unnamed: R20.1, RV12.2

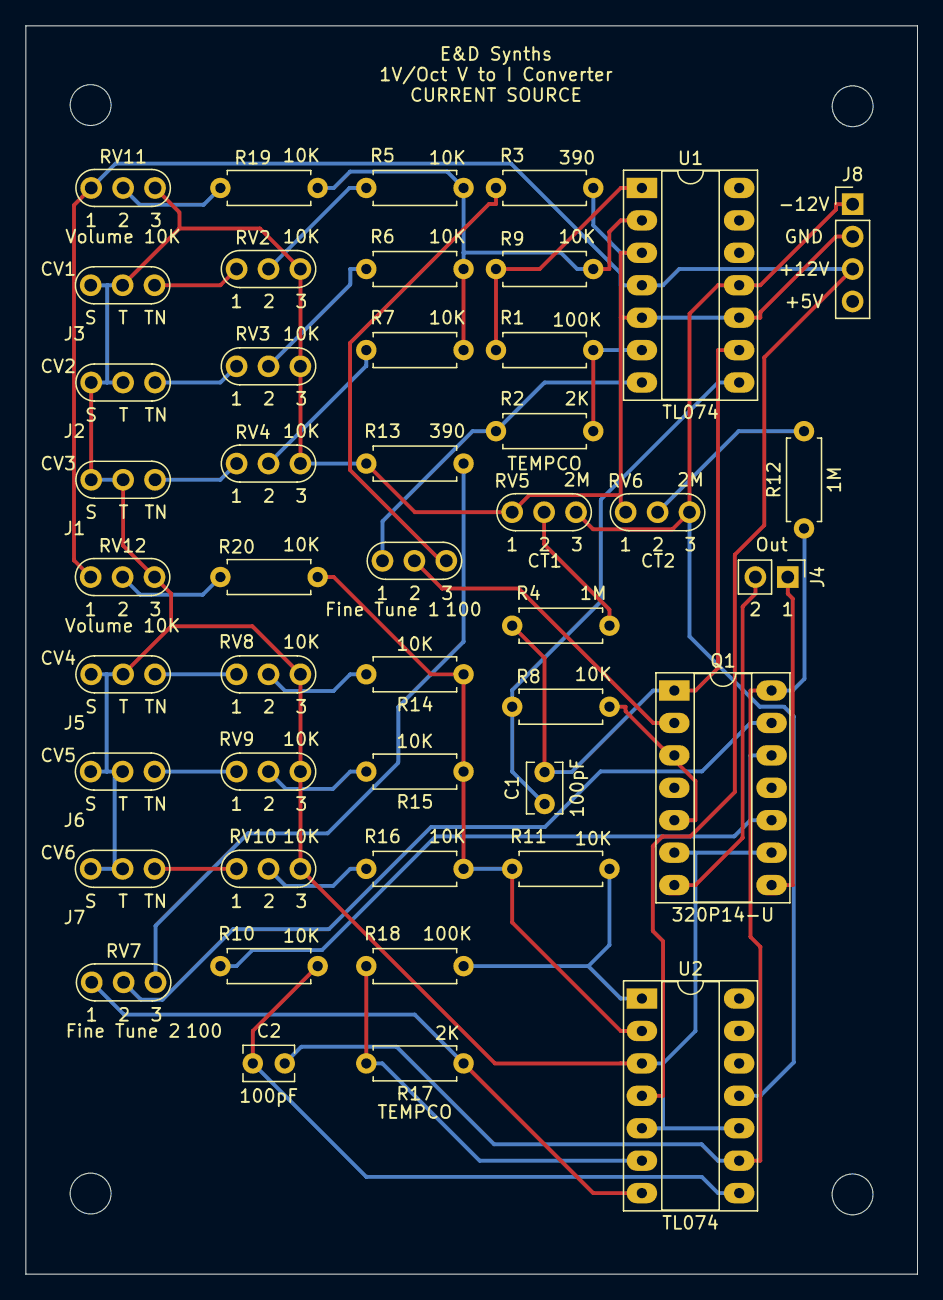
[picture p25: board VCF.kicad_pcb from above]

Board: 2 copper layers, 69.8 x 97.8 mm, 45 parts (0 on the bottom side), 39 nets.

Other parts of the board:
Fine Tune 1: 100; Pot_Small_Mounting_W7.0mm_H2.5mm

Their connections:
unnamed 16: Fine Tune 1.2; also elsewhere on the board
unnamed 24: Fine Tune 1.1; also elsewhere on the board
unnamed 25: Fine Tune 1.3; also elsewhere on the board

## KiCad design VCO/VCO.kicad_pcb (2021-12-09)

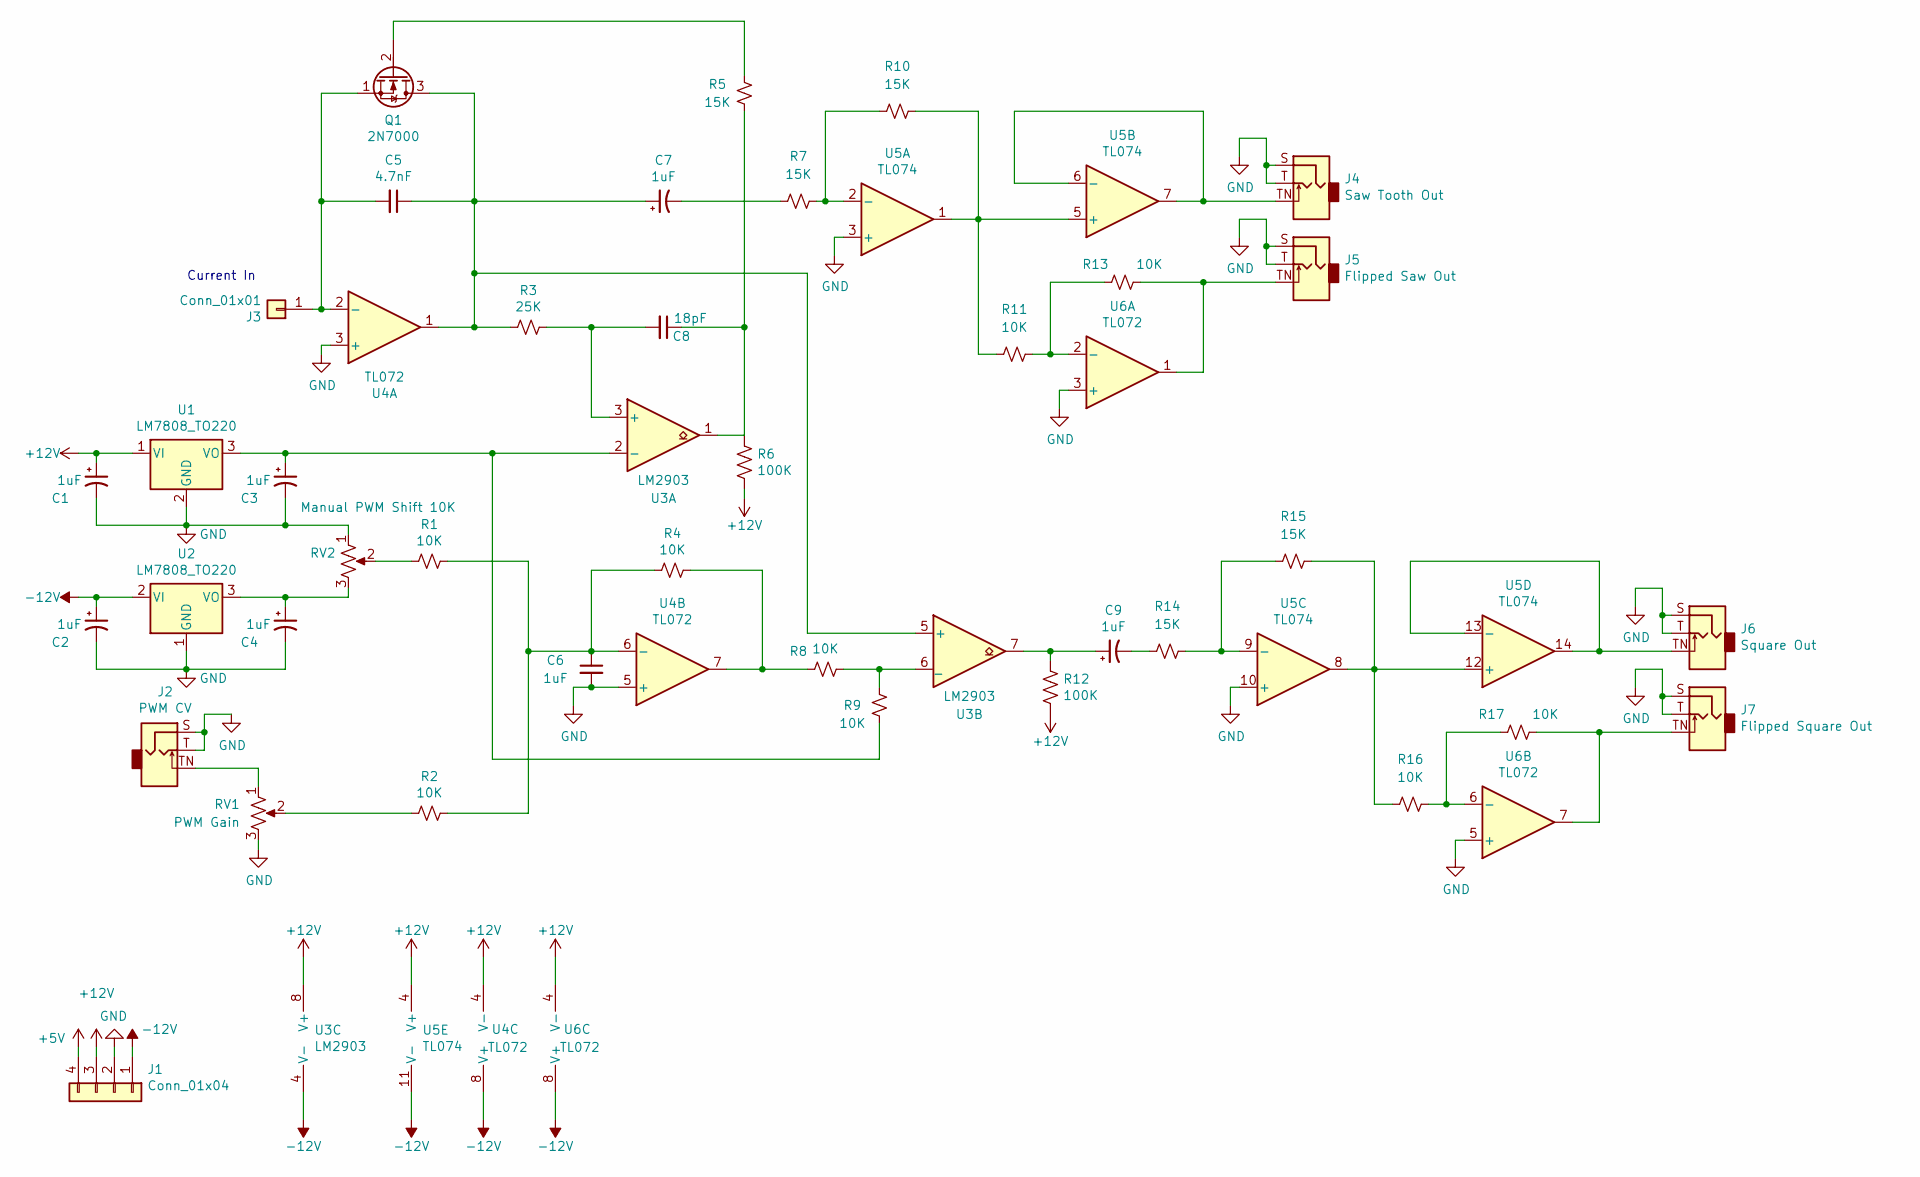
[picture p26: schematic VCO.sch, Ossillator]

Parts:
C1, C2, C3, C4: 1uF; CP_Radial_Tantal_D4.5mm_P2.50mm
C5: 4.7nF; C_Disc_D6.0mm_W2.5mm_P5.00mm
C6: 1uF; C_Disc_D6.0mm_W2.5mm_P5.00mm
C7, C9: 1uF; CP_Radial_D6.3mm_P2.50mm
C8: 18pF; C_Disc_D3.4mm_W2.1mm_P2.50mm
J1: Conn_01x04; PinHeader_1x04_P2.54mm_Vertical
J2: PWM CV; Thonkiconn_Audio_Jack_PJ398SM_W7.0mm_H2.5mm
J3: Conn_01x01; PinHeader_1x01_P2.54mm_Vertical
J4: Saw Tooth Out; Thonkiconn_Audio_Jack_PJ398SM_W7.0mm_H2.5mm
J5: Flipped Saw Out; Thonkiconn_Audio_Jack_PJ398SM_W7.0mm_H2.5mm
J6: Square Out; Thonkiconn_Audio_Jack_PJ398SM_W7.0mm_H2.5mm
J7: Flipped Square Out; Thonkiconn_Audio_Jack_PJ398SM_W7.0mm_H2.5mm
Q1: 2N7000; TO-92L_HandSolder
R1, R2, R4, R8, R9, R11, R13, R16, R17: 10K; R_Axial_DIN0207_L6.3mm_D2.5mm_P7.62mm_Horizontal
R3: 25K; R_Axial_DIN0207_L6.3mm_D2.5mm_P7.62mm_Horizontal
R5, R7, R10, R14, R15: 15K; R_Axial_DIN0207_L6.3mm_D2.5mm_P7.62mm_Horizontal
R6, R12: 100K; R_Axial_DIN0207_L6.3mm_D2.5mm_P7.62mm_Horizontal
RV1: PWM Gain; Pot_Small_Mounting_W7.0mm_H2.5mm
RV2: Manual PWM Shift 10K; Pot_Small_Mounting_W7.0mm_H2.5mm
U1, U2: LM7808_TO220; TO-220-3_Vertical
U3: LM2903; DIP-8_W7.62mm_Socket_LongPads
U4, U6: TL072; DIP-8_W7.62mm_Socket_LongPads
U5: TL074; DIP-14_W7.62mm_Socket_LongPads

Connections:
+5V: J1.4
+12V: C1.1, J1.3, R6.2, R12.2, U1.1 (VI), U3.8 (V+), U4.4 (V-), U5.4 (V+), U6.4 (V-)
-12V: C2.1, J1.1, U2.2 (VI), U3.4 (V-), U4.8 (V+), U5.11 (V-), U6.8 (V+)
GND: C1.2, C2.2, C3.2, C4.2, C6.2, J1.2, J2.S, J2.T, J4.S, J4.T, J5.S, J5.T, J6.S, J6.T, J7.S, J7.T, RV1.3, RV2.1, U1.2 (GND), U2.1 (GND), U4.3 (+), U4.5 (+), U5.3 (+), U5.10 (+), U6.3 (+), U6.5 (+)
unnamed: C3.1, R9.2, U1.3 (VO), U3.2 (-)
unnamed: C4.1, RV2.3, U2.3 (VO)
unnamed: C5.1, C7.1, Q1.3 (D), R3.2, U3.5 (+), U4.1
unnamed: C5.2, J3.1, Q1.1 (S), U4.2 (-)
unnamed: C6.1, R1.1, R2.1, R4.2, U4.6 (-)
unnamed: C7.2, R7.2
unnamed: C8.1, R5.2, R6.1, U3.1
unnamed: C8.2, R3.1, U3.3 (+)
unnamed: C9.1, R12.1, U3.7
unnamed: C9.2, R14.2
unnamed: J2.TN, RV1.1
unnamed: J4.TN, U5.6 (-), U5.7
unnamed: J5.TN, R13.1, U6.1
unnamed: J6.TN, U5.13 (-), U5.14
unnamed: J7.TN, R17.1, U6.7
unnamed: Q1.2 (G), R5.1
unnamed: R1.2, RV2.2
unnamed: R2.2, RV1.2
unnamed: R4.1, R8.2, U4.7
unnamed: R8.1, R9.1, U3.6 (_)
unnamed: R10.1, R11.2, U5.1, U5.5 (+)
unnamed: R7.1, R10.2, U5.2 (-)
unnamed: R11.1, R13.2, U6.2 (-)
unnamed: R14.1, R15.2, U5.9 (-)
unnamed: R15.1, R16.2, U5.8, U5.12 (+)
unnamed: R16.1, R17.2, U6.6 (-)

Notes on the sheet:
Current In

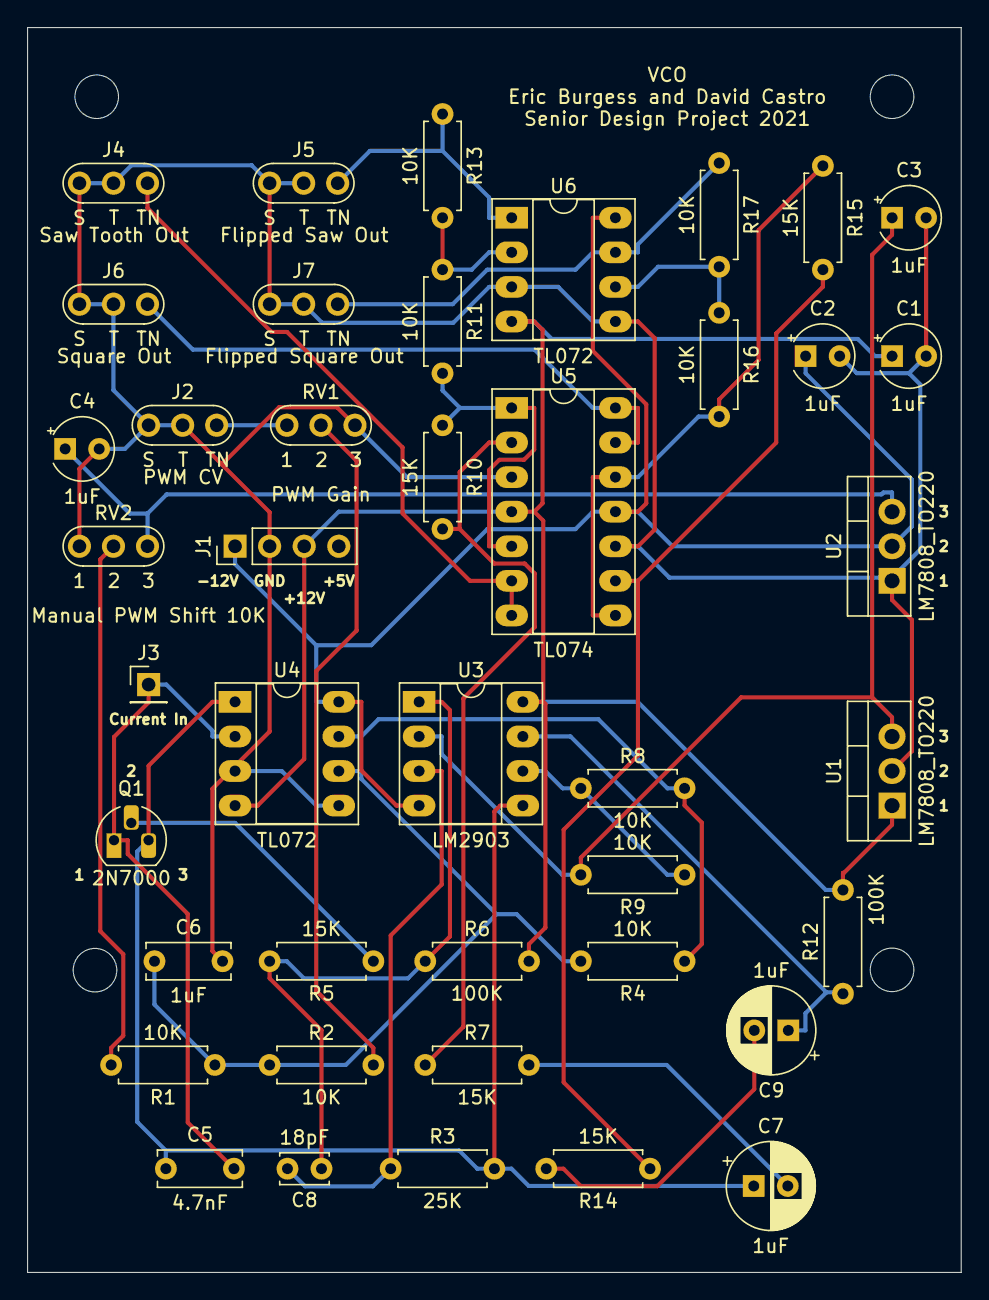
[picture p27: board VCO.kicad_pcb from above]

Board: 2 copper layers, 68.6 x 91.4 mm, 42 parts (0 on the bottom side), 29 nets.

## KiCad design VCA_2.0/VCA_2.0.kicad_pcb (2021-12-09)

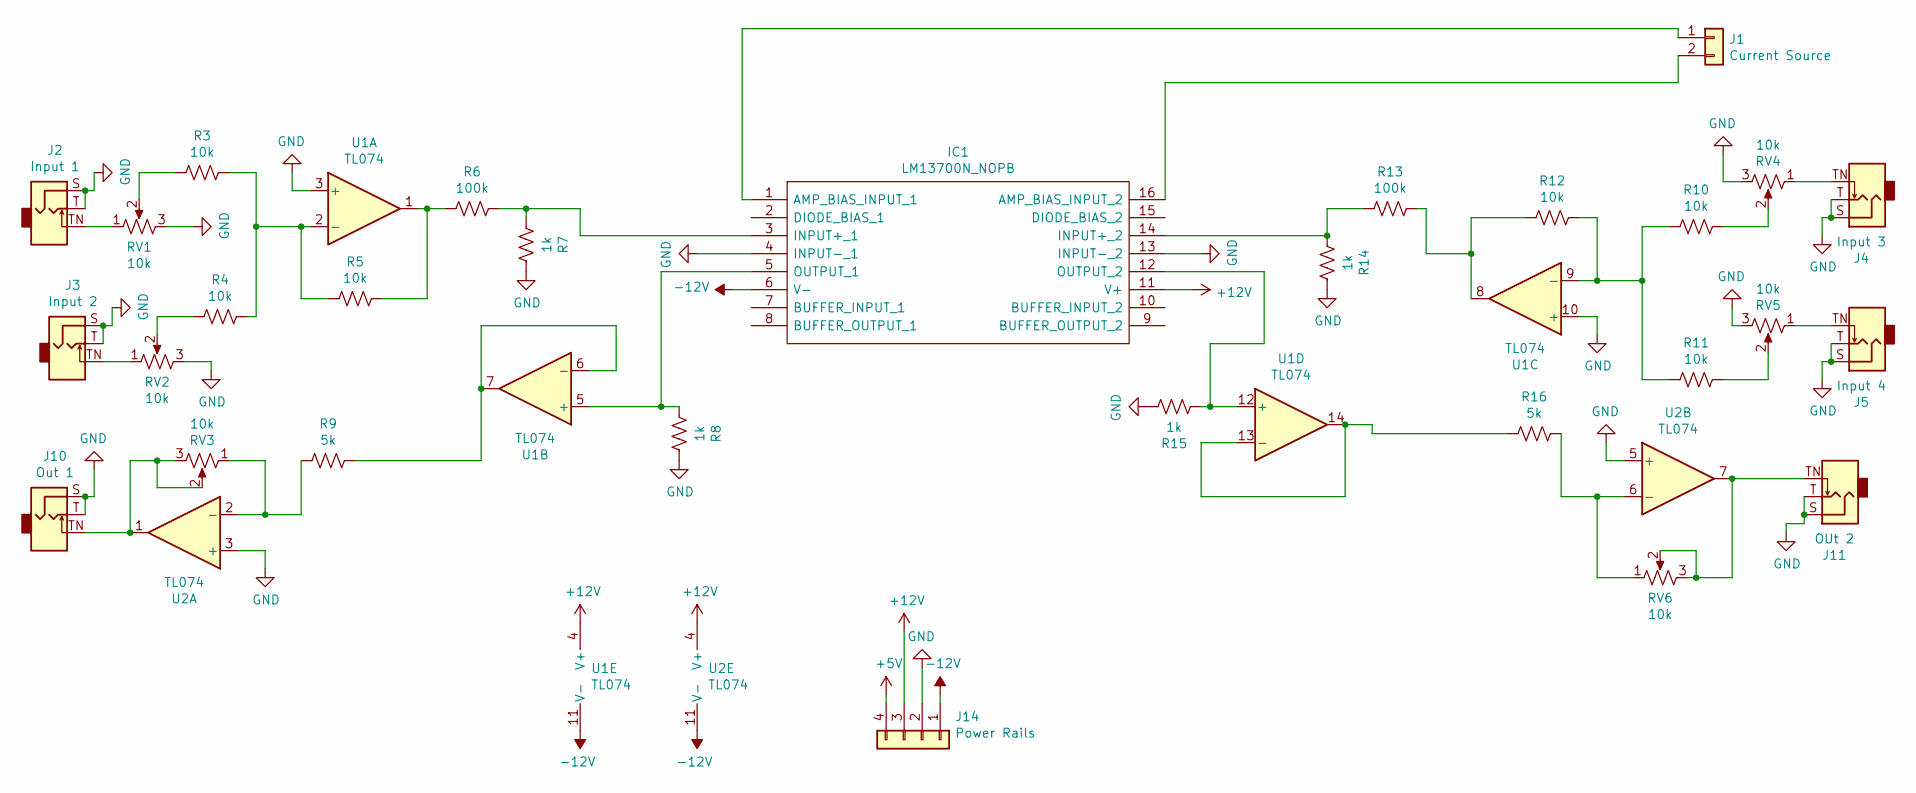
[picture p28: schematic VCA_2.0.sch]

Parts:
IC1: LM13700N_NOPB; DIP-16_W7.62mm_Socket_LongPads; Mouser Part Number 926-LM13700N/NOPB
J1: Current Source; PinHeader_1x02_P2.54mm_Vertical
J2: Input 1; THONK-AudioJack-PJ398SM-W3.5mm
J3: Input 2; THONK-AudioJack-PJ398SM-W3.5mm
J4: Input 3; THONK-AudioJack-PJ398SM-W3.5mm
J5: Input 4; THONK-AudioJack-PJ398SM-W3.5mm
J10: Out 1; THONK-AudioJack-PJ398SM-W3.5mm
J11: OUt 2; THONK-AudioJack-PJ398SM-W3.5mm
J14: Power Rails; PinHeader_1x04_P2.54mm_Vertical
R3, R4, R5, R10, R11, R12: 10k; R_Axial_DIN0207_L6.3mm_D2.5mm_P7.62mm_Horizontal
R6, R13: 100k; R_Axial_DIN0207_L6.3mm_D2.5mm_P7.62mm_Horizontal
R7, R8, R14, R15: 1k; R_Axial_DIN0207_L6.3mm_D2.5mm_P7.62mm_Horizontal
R9, R16: 5k; R_Axial_DIN0207_L6.3mm_D2.5mm_P7.62mm_Horizontal
RV1, RV2, RV3, RV4, RV5, RV6: 10k; POT_3_THT
U1, U2: TL074; DIP-14_W7.62mm_Socket_LongPads

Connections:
+5V: J14.4
+12V: IC1.11 (V+), J14.3, U1.4 (V+), U2.4 (V+)
-12V: IC1.6 (V-), J14.1, U1.11 (V-), U2.11 (V-)
GND: IC1.4 (INPUT-_1), IC1.13 (INPUT-_2), J2.S, J2.T, J3.S, J3.T, J4.S, J4.T, J5.S, J5.T, J10.S, J10.T, J11.S, J11.T, J14.2, R7.1, R8.1, R14.1, R15.1, RV1.3, RV2.3, RV4.3, RV5.3, U1.3 (+), U1.10 (+), U2.3 (+), U2.5 (+)
unnamed: IC1.1 (AMP_BIAS_INPUT_1), J1.1
unnamed: IC1.3 (INPUT+_1), R6.1, R7.2
unnamed: IC1.5 (OUTPUT_1), R8.2, U1.5 (+)
unnamed: IC1.12 (OUTPUT_2), R15.2, U1.12 (+)
unnamed: IC1.14 (INPUT+_2), R13.2, R14.2
unnamed: IC1.16 (AMP_BIAS_INPUT_2), J1.2
unnamed: J2.TN, RV1.1
unnamed: J3.TN, RV2.1
unnamed: J4.TN, RV4.1
unnamed: J5.TN, RV5.1
unnamed: J10.TN, RV3.2, RV3.3, U2.1
unnamed: J11.TN, RV6.2, RV6.3, U2.7
unnamed: R3.1, R4.1, R5.2, U1.2 (-)
unnamed: R3.2, RV1.2
unnamed: R4.2, RV2.2
unnamed: R5.1, R6.2, U1.1
unnamed: R9.1, U1.6 (-), U1.7
unnamed: R9.2, RV3.1, U2.2 (-)
unnamed: R10.1, RV4.2
unnamed: R10.2, R11.2, R12.1, U1.9 (-)
unnamed: R11.1, RV5.2
unnamed: R12.2, R13.1, U1.8
unnamed: R16.1, RV6.1, U2.6 (-)
unnamed: R16.2, U1.13 (-), U1.14

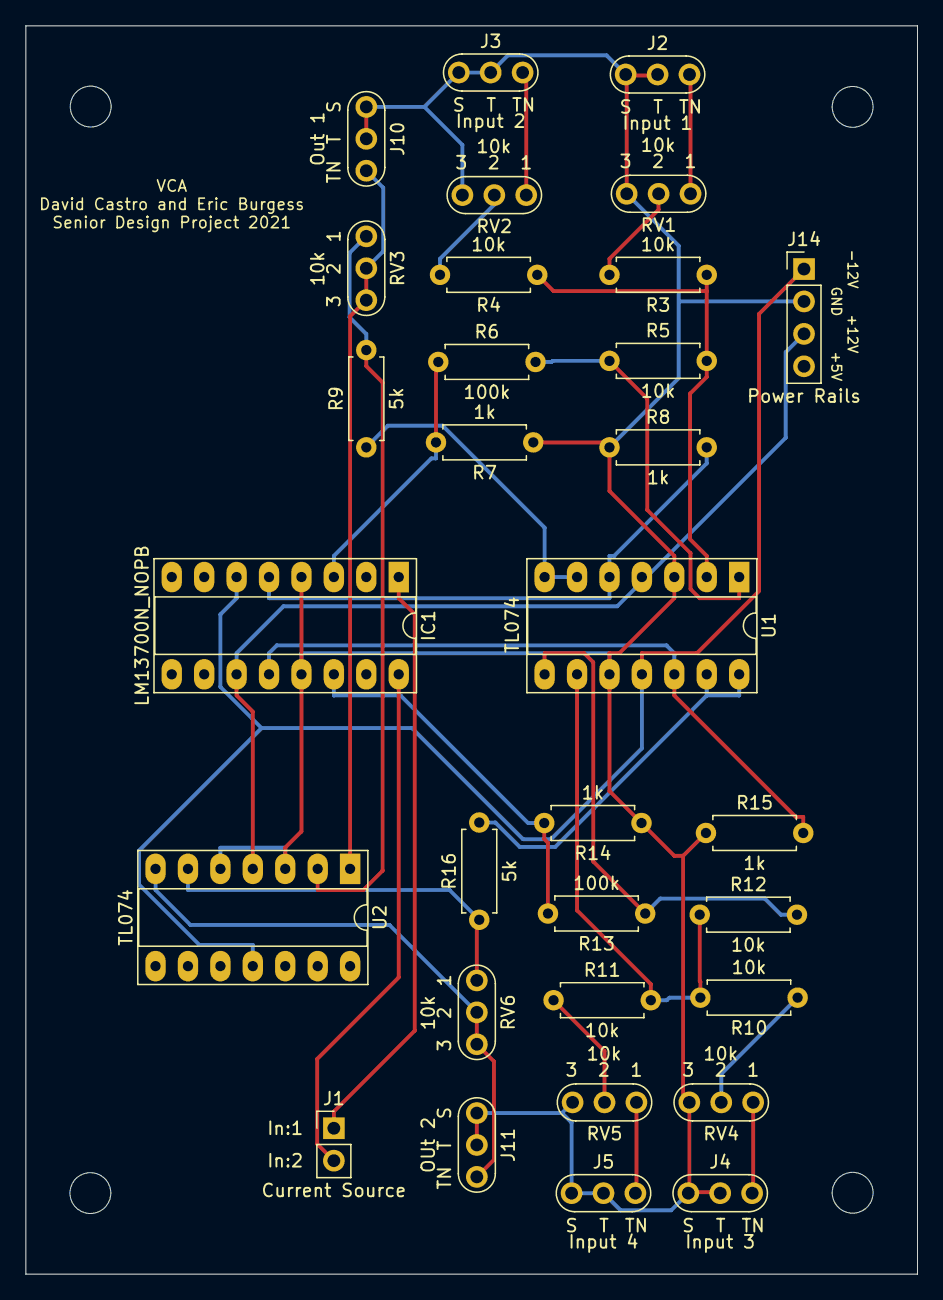
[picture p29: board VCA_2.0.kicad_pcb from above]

Board: 2 copper layers, 69.9 x 97.8 mm, 31 parts (0 on the bottom side), 27 nets.

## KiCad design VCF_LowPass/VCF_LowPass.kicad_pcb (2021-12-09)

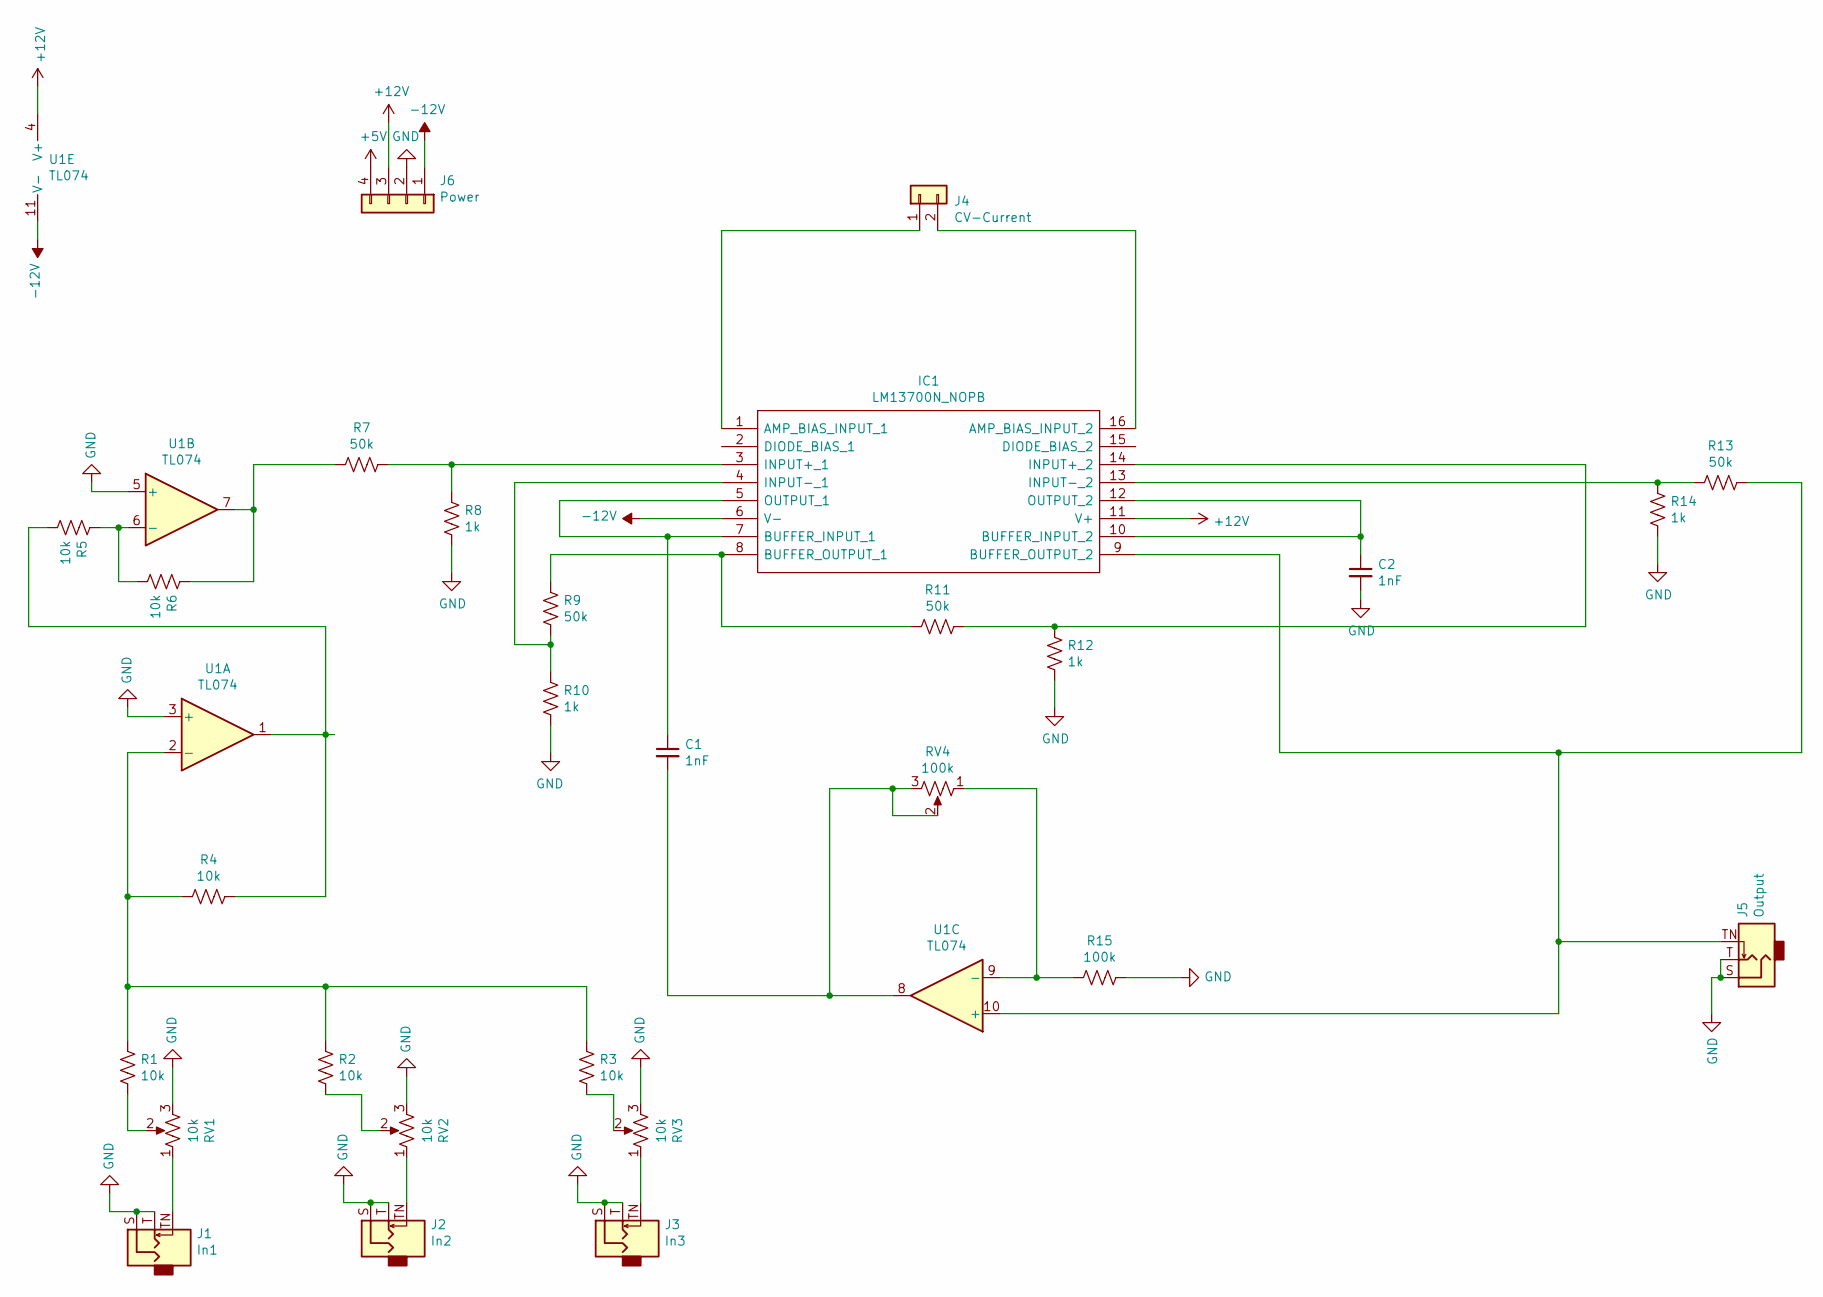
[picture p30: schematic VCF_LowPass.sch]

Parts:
C1: 1nF; Resonator-3Pin_W7.0mm_H2.5mm
C2: 1nF; C_Disc_D3.8mm_W2.6mm_P2.50mm
IC1: LM13700N_NOPB; DIP-16_W7.62mm_Socket_LongPads; Mouser Part Number 926-LM13700N/NOPB
J1: In1; THONK-AudioJack-PJ398SM-W3.5mm
J2: In2; THONK-AudioJack-PJ398SM-W3.5mm
J3: In3; THONK-AudioJack-PJ398SM-W3.5mm
J4: CV-Current; PinHeader_1x02_P2.54mm_Vertical
J5: Output; THONK-AudioJack-PJ398SM-W3.5mm
J6: Power; PinHeader_1x04_P2.54mm_Vertical
R1, R2, R3, R4, R5, R6: 10k; R_Axial_DIN0207_L6.3mm_D2.5mm_P7.62mm_Horizontal
R7, R9, R11, R13: 50k; R_Axial_DIN0207_L6.3mm_D2.5mm_P7.62mm_Horizontal
R8, R10, R12, R14: 1k; R_Axial_DIN0207_L6.3mm_D2.5mm_P7.62mm_Horizontal
R15: 100k; R_Axial_DIN0207_L6.3mm_D2.5mm_P7.62mm_Horizontal
RV1, RV2, RV3: 10k; POT_3_THT
RV4: 100k; POT_3_THT
U1: TL074; DIP-14_W7.62mm_Socket_LongPads

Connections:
+5V: J6.4
+12V: IC1.11 (V+), J6.3, U1.4 (V+)
-12V: IC1.6 (V-), J6.1, U1.11 (V-)
GND: C2.2, J1.S, J1.T, J2.S, J2.T, J3.S, J3.T, J5.S, J5.T, J6.2, R8.1, R10.1, R12.1, R14.1, R15.1, RV1.3, RV2.3, RV3.3, U1.3 (+), U1.5 (+)
unnamed: C1.1, IC1.5 (OUTPUT_1), IC1.7 (BUFFER_INPUT_1)
unnamed: C1.2, RV4.2, RV4.3, U1.8
unnamed: C2.1, IC1.10 (BUFFER_INPUT_2), IC1.12 (OUTPUT_2)
unnamed: IC1.1 (AMP_BIAS_INPUT_1), J4.1
unnamed: IC1.3 (INPUT+_1), R7.1, R8.2
unnamed: IC1.4 (INPUT-_1), R9.1, R10.2
unnamed: IC1.8 (BUFFER_OUTPUT_1), R9.2, R11.2
unnamed: IC1.9 (BUFFER_OUTPUT_2), J5.TN, R13.2, U1.10 (+)
unnamed: IC1.13 (INPUT-_2), R13.1, R14.2
unnamed: IC1.14 (INPUT+_2), R11.1, R12.2
unnamed: IC1.16 (AMP_BIAS_INPUT_2), J4.2
unnamed: J1.TN, RV1.1
unnamed: J2.TN, RV2.1
unnamed: J3.TN, RV3.1
unnamed: R1.1, RV1.2
unnamed: R1.2, R2.2, R3.2, R4.2, U1.2 (-)
unnamed: R2.1, RV2.2
unnamed: R3.1, RV3.2
unnamed: R4.1, R5.1, U1.1
unnamed: R5.2, R6.1, U1.6 (-)
unnamed: R6.2, R7.2, U1.7
unnamed: R15.2, RV4.1, U1.9 (-)

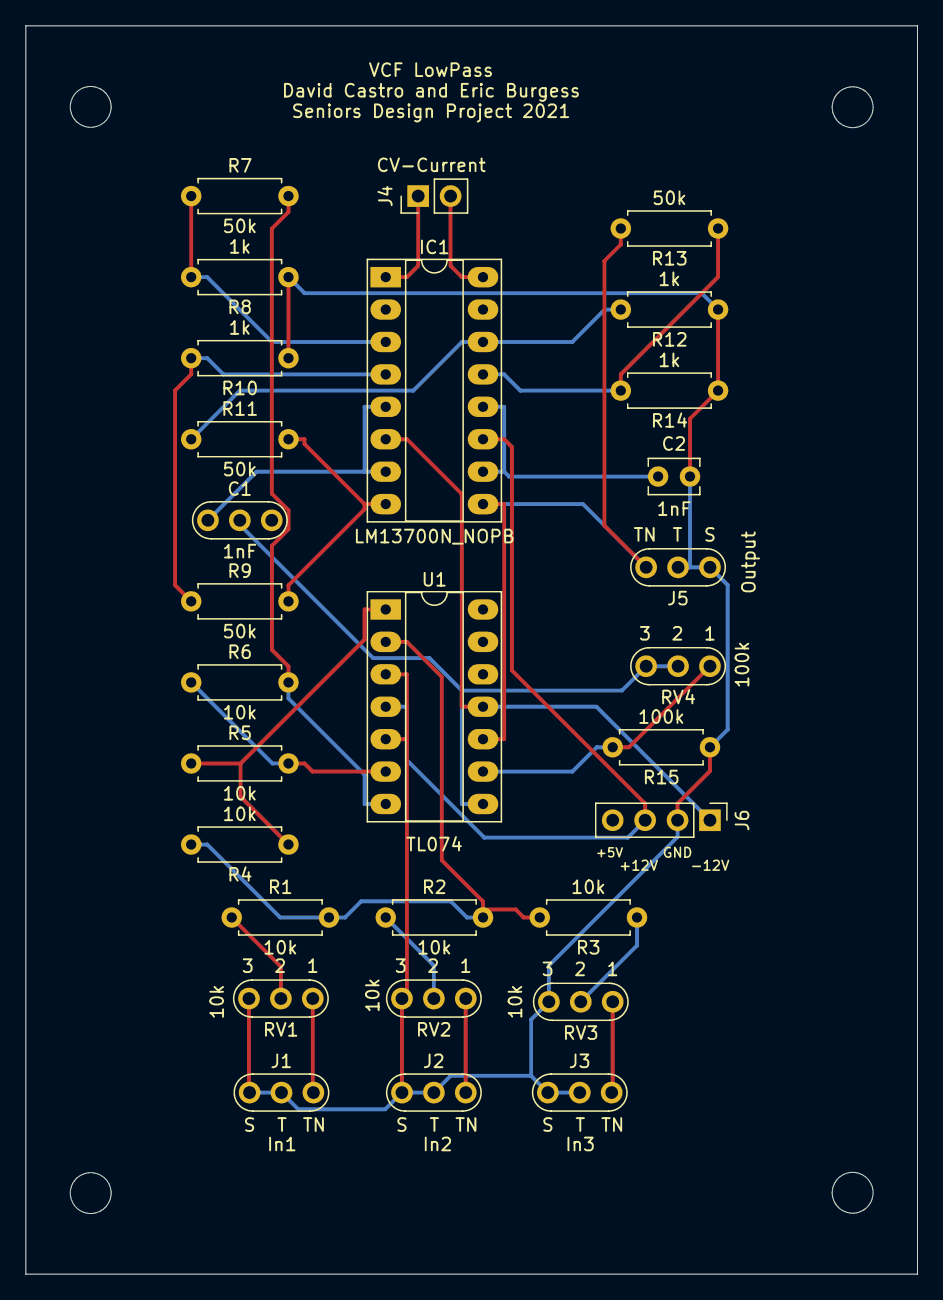
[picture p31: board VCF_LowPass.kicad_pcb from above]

Board: 2 copper layers, 69.8 x 97.8 mm, 29 parts (0 on the bottom side), 25 nets.

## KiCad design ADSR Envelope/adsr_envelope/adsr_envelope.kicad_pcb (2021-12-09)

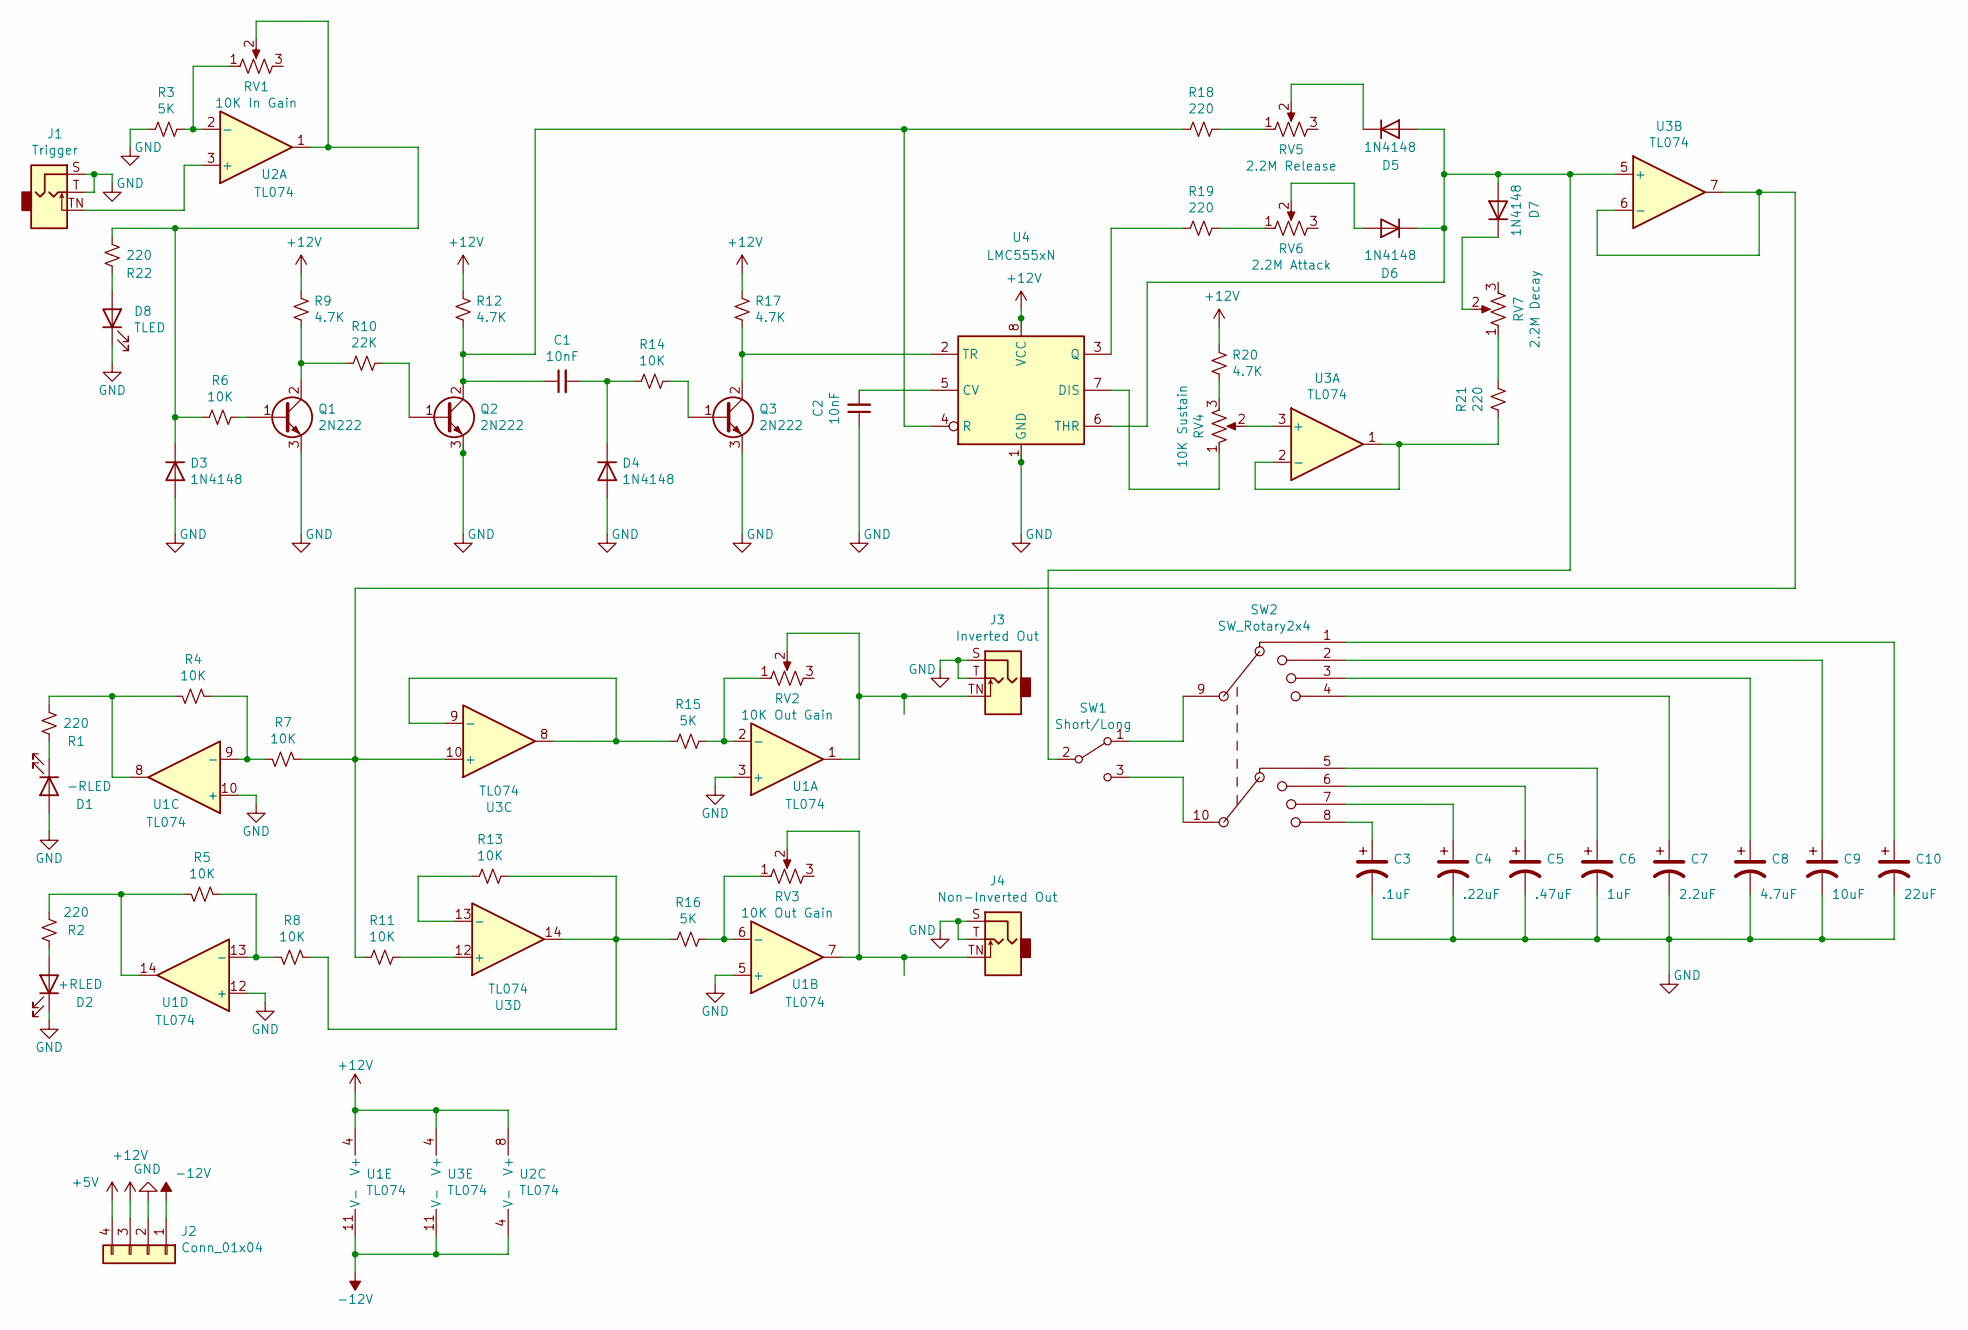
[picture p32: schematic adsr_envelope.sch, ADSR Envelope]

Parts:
C1, C2: 10nF; C_Disc_D6.0mm_W2.5mm_P5.00mm
C3: .1uF; CP_Radial_D6.3mm_P2.50mm
C4: .22uF; CP_Radial_D6.3mm_P2.50mm
C5: .47uF; CP_Radial_D6.3mm_P2.50mm
C6: 1uF; CP_Radial_D6.3mm_P2.50mm
C7: 2.2uF; CP_Radial_D6.3mm_P2.50mm
C8: 4.7uF; CP_Radial_D6.3mm_P2.50mm
C9: 10uF; CP_Radial_D6.3mm_P2.50mm
C10: 22uF; CP_Radial_D6.3mm_P2.50mm
D1: -RLED; LED_D3.0mm
D2: +RLED; LED_D3.0mm
D3, D4, D5, D6, D7: 1N4148; D_A-405_P7.62mm_Horizontal
D8: TLED; LED_D3.0mm
J1: Trigger; Thonkiconn_Audio_Jack_PJ398SM_W7.0mm_H2.5mm
J2: Conn_01x04; PinHeader_1x04_P2.54mm_Vertical
J3: Inverted Out; Thonkiconn_Audio_Jack_PJ398SM_W7.0mm_H2.5mm
J4: Non-Inverted Out; Thonkiconn_Audio_Jack_PJ398SM_W7.0mm_H2.5mm
Q1, Q2, Q3: 2N222; TO-92L_HandSolder
R1, R2, R18, R19, R21, R22: 220; R_Axial_DIN0207_L6.3mm_D2.5mm_P7.62mm_Horizontal
R3, R15, R16: 5K; R_Axial_DIN0207_L6.3mm_D2.5mm_P7.62mm_Horizontal
R4, R5, R6, R7, R8, R11, R13, R14: 10K; R_Axial_DIN0207_L6.3mm_D2.5mm_P7.62mm_Horizontal
R9, R12, R17, R20: 4.7K; R_Axial_DIN0207_L6.3mm_D2.5mm_P7.62mm_Horizontal
R10: 22K; R_Axial_DIN0207_L6.3mm_D2.5mm_P7.62mm_Horizontal
RV1: 10K In Gain; Pot_Small_Mounting_W7.0mm_H2.5mm
RV2, RV3: 10K Out Gain; Pot_Small_Mounting_W7.0mm_H2.5mm
RV4: 10K Sustain; Pot_Small_Mounting_W7.0mm_H2.5mm
RV5: 2.2M Release; Pot_Small_Mounting_W7.0mm_H2.5mm
RV6: 2.2M Attack; Pot_Small_Mounting_W7.0mm_H2.5mm
RV7: 2.2M Decay; Pot_Small_Mounting_W7.0mm_H2.5mm
SW1: Short/Long; PinHeader_1x03_P2.54mm_Vertical
SW2: SW_Rotary2x4; PinHeader_1x10_P2.54mm_Vertical
U1, U3: TL074; DIP-14_W7.62mm_Socket_LongPads
U2: TL074; DIP-8_W7.62mm_Socket_LongPads
U4: LMC555xN; DIP-8_W7.62mm_Socket_LongPads

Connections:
+5V: J2.4
+12V: J2.3, R9.1, R12.1, R17.1, R20.1, U1.4 (V+), U2.8 (V+), U3.4 (V+), U4.8 (VCC)
-12V: J2.1, U1.11 (V-), U2.4 (V-), U3.11 (V-)
GND: C2.1, C3.2, C4.2, C5.2, C6.2, C7.2, C8.2, C9.2, C10.2, D1.2 (A), D2.1 (K), D3.2 (A), D4.2 (A), D8.1 (K), J1.S, J1.T, J2.2, J3.S, J3.T, J4.S, J4.T, Q1.3 (E), Q2.3 (E), Q3.3 (E), R3.1, U1.3 (+), U1.5 (+), U1.10 (+), U1.12 (+), U4.1 (GND)
unnamed: C1.1, Q2.2 (C), R12.2, R18.1, U4.4 (R)
unnamed: C1.2, D4.1 (K), R14.2
unnamed: C2.2, U4.5 (CV)
unnamed: C3.1, SW2.8
unnamed: C4.1, SW2.7
unnamed: C5.1, SW2.6
unnamed: C6.1, SW2.5
unnamed: C7.1, SW2.4
unnamed: C8.1, SW2.3
unnamed: C9.1, SW2.2
unnamed: C10.1, SW2.1
unnamed: D1.1 (K), R1.2
unnamed: D2.2 (A), R2.2
unnamed: D3.1 (K), R6.2, R22.1, RV1.2, U2.1
unnamed: D5.1 (K), RV5.2
unnamed: D5.2 (A), D6.1 (K), D7.2 (A), SW1.2 (B), U3.5 (+), U4.6 (THR)
unnamed: D6.2 (A), RV6.2
unnamed: D7.1 (K), RV7.2
unnamed: D8.2 (A), R22.2
unnamed: J1.TN, U2.3 (+)
unnamed: J3.TN, RV2.2, U1.1
unnamed: J4.TN, RV3.2, U1.7
unnamed: Q1.1 (B), R6.1
unnamed: Q1.2 (C), R9.2, R10.1
unnamed: Q2.1 (B), R10.2
unnamed: Q3.1 (B), R14.1
unnamed: Q3.2 (C), R17.2, U4.2 (TR)
unnamed: R1.1, R4.2, U1.8
unnamed: R2.1, R5.2, U1.14
unnamed: R3.2, RV1.1, U2.2 (-)
unnamed: R4.1, R7.2, U1.9 (-)
unnamed: R5.1, R8.2, U1.13 (-)
unnamed: R7.1, R11.1, U3.6 (-), U3.7, U3.10 (+)
unnamed: R11.2, U3.12 (+)
unnamed: R13.1, U3.13 (-)
unnamed: R8.1, R13.2, R16.1, U3.14
unnamed: R15.1, U3.8, U3.9 (-)
unnamed: R15.2, RV2.1, U1.2 (-)
unnamed: R16.2, RV3.1, U1.6 (-)
unnamed: R18.2, RV5.1
unnamed: R19.1, U4.3 (Q)
unnamed: R19.2, RV6.1
unnamed: R20.2, RV4.3
unnamed: R21.1, U3.1, U3.2 (-)
unnamed: R21.2, RV7.1
unnamed: RV4.1, U4.7 (DIS)
unnamed: RV4.2, U3.3 (+)
unnamed: SW1.1 (A), SW2.9
unnamed: SW1.3 (C), SW2.10

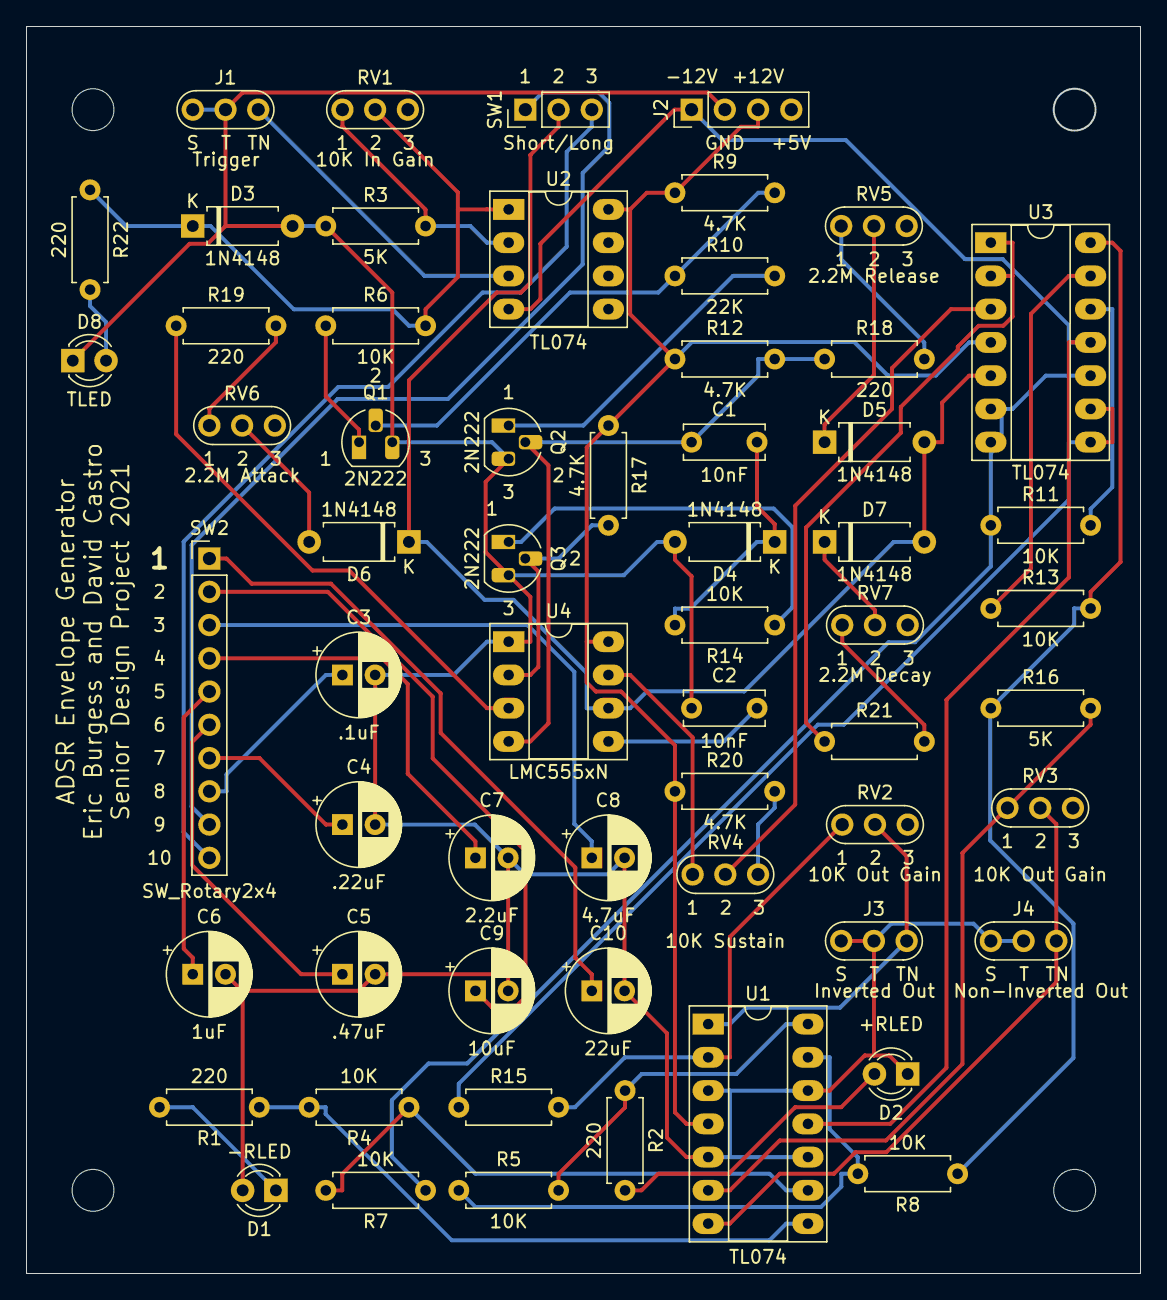
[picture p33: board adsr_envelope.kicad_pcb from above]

Board: 2 copper layers, 85.1 x 95.2 mm, 60 parts (0 on the bottom side), 52 nets.
